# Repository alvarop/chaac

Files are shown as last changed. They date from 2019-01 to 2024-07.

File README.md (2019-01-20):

# Chaac - Weather station!

This is a work in progress for a wireless weather station project.

The project consists of:

* [Hardware](hw/) - Main development board design files
* [Firmware](fw/) - Code for the microcontroller
* [Software](sw/) - Python scripts to communicate with the weather station, log, and plot data

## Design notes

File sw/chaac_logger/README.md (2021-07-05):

# Chaac Logger Setup

## On Raspberry Pi

1. Clone repo to raspberry pi (or scp it over)
2. Run `./support/install_dependencies.sh` to get required software
3. Run `./support/setup.sh` to configure everything and start the server

If you just changed a few files and don't want to go through the whole pipenv process again, you can use `./support/update.sh`. This will just restart the services.

### Monitoring
To monitor packets arriving run:

`sudo tail -f /var/log/supervisor/chaac-logger-app-stdout---supervisor-KsDl4b.log`

Note that the last few characters, `KsDl4b` in this case, change everytime supervisor restarts. It's easy to just tab complete with whatever is there.

To check for errors, just replace stdout for stderr in the command.

## Local Development
Run `pipenv run python chaac_logger.py --port /dev/ttyUSB0 --db sqlite_db_filename.db`

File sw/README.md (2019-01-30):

# Chaac Software

## [chaac](chaac/)
The chaac directory has python files related to chaac packets and processing.

## [chaac_frontend](chaac_frontend/)
The chaac_frontend is a flask project with the web ui for Chaac. It displays the current weather as well as plots historical data

## [chaac_logger](chaac_logger/)
The chaac_logger takes care of receiving the serial data from the xbee radio, decoding, and saving it into the database.

## [scripts](scripts/)
The scripts directory has various useful (and in development) scripts.

## [serial_packet](serial_packet/)
The serial_packet directory has python files related to serial packets (one layer below the chaac packets).

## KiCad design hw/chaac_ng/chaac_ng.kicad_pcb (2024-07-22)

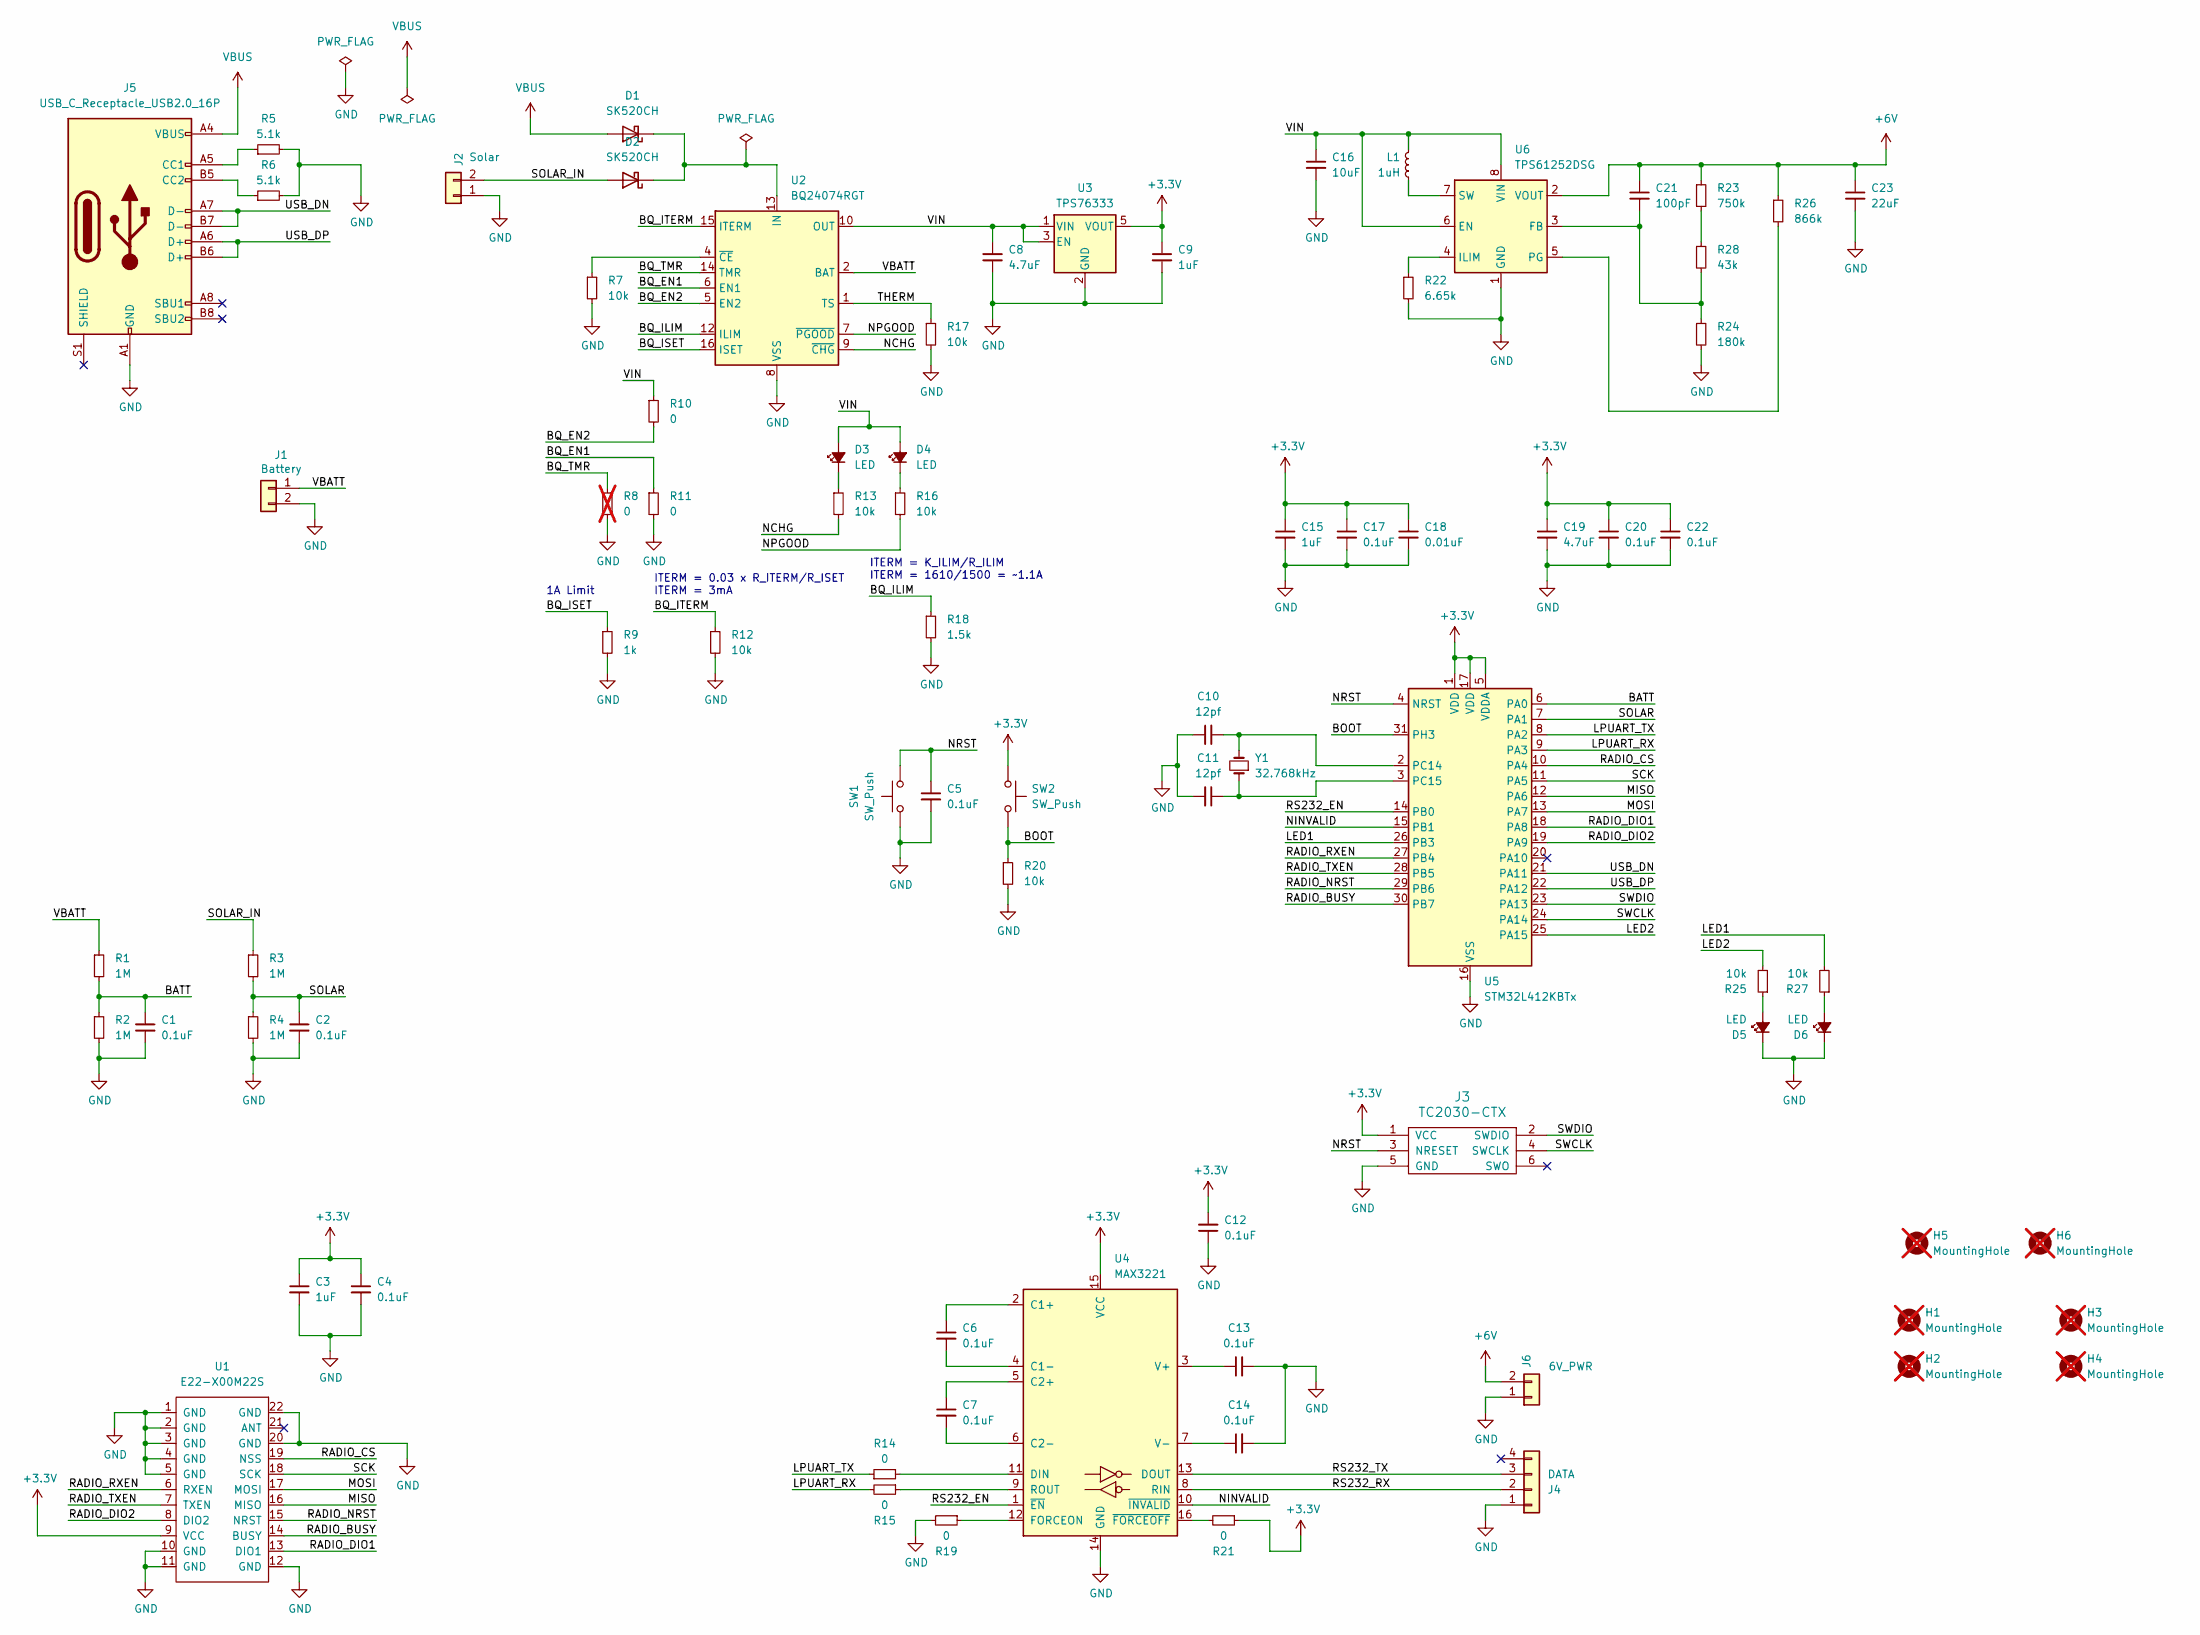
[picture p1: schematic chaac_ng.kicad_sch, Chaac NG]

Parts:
C1, C2, C4, C5, C6, C7, C12, C13, C14, C17, C20, C22: 0.1uF; C_0402_1005Metric; MPN CL05B104KB54PNC; LCSC C307331
C3, C9, C15: 1uF; C_0402_1005Metric; MPN CL05A105KA5NQNC; LCSC C52923
C8, C19: 4.7uF; C_0402_1005Metric; MPN CL05A475MP5NRNC; LCSC C23733
C10, C11: 12pf; C_0402_1005Metric; MPN 0402CG120J500NT; LCSC C1547
C16: 10uF; C_0603_1608Metric; MPN CL10A106MA8NRNC; LCSC C96446
C18: 0.01uF; C_0402_1005Metric; MPN CL05B103KB5NNNC; LCSC C15195
C21: 100pF; C_0402_1005Metric; MPN 0402CG101J500NT; LCSC C1546
C23: 22uF; C_1210_3225Metric; MPN TMK325B7226KMHP; LCSC C386098
D1, D2: SK520CH; SK520_DO-214AB; MPN SK520CHV6G; LCSC C483994
D3, D4, D5, D6: LED; LED_0603_1608Metric; MPN KT-0603R; LCSC C2286
H1, H2, H3, H4: MountingHole; MountingHole_3.2mm_M3; not fitted
H5, H6: MountingHole; ZIPTIE_HOLE_4x2mm; not fitted
J1: Battery; S2B-PH-SM4-TB; MPN S2B-PH-SM4-TB(LF)(SN); LCSC C295747
J2: Solar; TerminalBlock_TE_282834-2_1x02_P2.54mm_Horizontal; MPN 282834-2; LCSC C918120
J3: TC2030-CTX; TC2030-NL
J4: DATA; TerminalBlock_TE_282834-4_1x04_P2.54mm_Horizontal; MPN 282834-4; LCSC C918122
J5: USB_C_Receptacle_USB2.0_16P; USB-C-SMD_TYPE-C16PIN; MPN TYPE-C16PIN; LCSC C393939
J6: 6V_PWR; TerminalBlock_TE_282834-2_1x02_P2.54mm_Horizontal; MPN 282834-2; LCSC C918120
L1: 1uH; L_0806; MPN DFE201610E-1R0M=P2; LCSC C161082
R1, R2, R3, R4: 1M; R_0402_1005Metric; LCSC C26083
R5, R6: 5.1k; R_0402_1005Metric; LCSC C25905
R7, R12, R13, R16, R17, R20, R25, R27: 10k; R_0402_1005Metric; LCSC C25744
R8: 0; R_0402_1005Metric; LCSC C17168; not fitted
R9: 1k; R_0402_1005Metric; LCSC C11702
R10, R11, R14, R15, R19, R21: 0; R_0402_1005Metric; LCSC C17168
R18: 1.5k; R_0402_1005Metric; LCSC C25867
R22: 6.65k; R_0402_1005Metric; LCSC C227201
R23: 750k; R_0402_1005Metric; LCSC C137937
R24: 180k; R_0402_1005Metric; LCSC C138046
R26: 866k; R_0402_1005Metric; LCSC C227250
R28: 43k; R_0402_1005Metric; LCSC C227081
SW1, SW2: SW_Push; SW-SMD_L3.9-W3.0-P4.45; MPN SKRKAEE020; LCSC C115357
U1: E22-X00M22S; MPN E22-900M22S; LCSC C411293
U2: BQ24074RGT; VQFN-16-1EP_3x3mm_P0.5mm_EP1.6x1.6mm; MPN BQ24074RGTR; LCSC C54313
U3: TPS76333; SOT-23-5; MPN TCR3DF33,LM(CT; LCSC C146356
U4: MAX3221; TSSOP-16_4.4x5mm_P0.65mm; MPN MAX3221EIPWR; LCSC C484736
U5: STM32L412KBTx; LQFP-32_7x7mm_P0.8mm; MPN STM32L412KBT6; LCSC C529438
U6: TPS61252DSG; WSON-8-1EP_2x2mm_P0.5mm_EP0.9x1.6mm; MPN TPS61252DSGR; LCSC C128617
Y1: 32.768kHz; ABS05; MPN ABS05-32.768KHZ-9-T; LCSC C596929

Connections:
+3.3V: C3.1, C4.1, C9.1, C12.2, C15.1, C17.1, C18.1, C19.1, C20.1, C22.1, J3.1 (VCC), R21.1, SW2.1, U1.9 (VCC), U3.5 (VOUT), U4.15 (VCC), U5.1 (VDD), U5.5 (VDDA), U5.17 (VDD)
+6V: C21.1, C23.1, J6.2, R23.1, R26.1, U6.2 (VOUT)
/BATT: C1.1, R1.2, R2.1, U5.6 (PA0)
/BOOT: R20.1, SW2.2, U5.31 (PH3)
/BQ_EN1: R11.1, U2.6 (EN1)
/BQ_EN2: R10.2, U2.5 (EN2)
/BQ_ILIM: R18.1, U2.12 (ILIM)
/BQ_ISET: R9.1, U2.16 (ISET)
/BQ_ITERM: R12.1, U2.15 (ITERM)
/BQ_TMR: R8.1, U2.14 (TMR)
/LED1: R27.2, U5.26 (PB3)
/LED2: R25.2, U5.25 (PA15)
/LPUART_RX: R15.2, U5.9 (PA3)
/LPUART_TX: R14.1, U5.8 (PA2)
/MISO: U1.16 (MISO), U5.12 (PA6)
/MOSI: U1.17 (MOSI), U5.13 (PA7)
/NCHG: R13.2, U2.9 (~CHG)
/NINVALID: U4.10 (~INVALID), U5.15 (PB1)
/NPGOOD: R16.2, U2.7 (~PGOOD)
/NRST: C5.1, J3.3 (NRESET), SW1.2, U5.4 (NRST)
/RADIO_BUSY: U1.14 (BUSY), U5.30 (PB7)
/RADIO_CS: U1.19 (NSS), U5.10 (PA4)
/RADIO_DIO1: U1.13 (DIO1), U5.18 (PA8)
/RADIO_DIO2: U1.8 (DIO2), U5.19 (PA9)
/RADIO_NRST: U1.15 (NRST), U5.29 (PB6)
/RADIO_RXEN: U1.6 (RXEN), U5.27 (PB4)
/RADIO_TXEN: U1.7 (TXEN), U5.28 (PB5)
/RS232_EN: U4.1 (~EN), U5.14 (PB0)
/RS232_RX: J4.2, U4.8 (RIN)
/RS232_TX: J4.3, U4.13 (DOUT)
/SCK: U1.18 (SCK), U5.11 (PA5)
/SOLAR: C2.1, R3.2, R4.1, U5.7 (PA1)
/SOLAR_IN: D2.2 (A), J2.2, R3.1
/SWCLK: J3.4 (SWCLK), U5.24 (PA14)
/SWDIO: J3.2 (SWDIO), U5.23 (PA13)
/THERM: R17.1, U2.1 (TS)
/USB_DN: J5.A7 (D-), J5.B7 (D-), U5.21 (PA11)
/USB_DP: J5.A6 (D+), J5.B6 (D+), U5.22 (PA12)
/VBATT: J1.1, R1.1, U2.2 (BAT), U2.3 (BAT)
/VIN: C8.1, C16.1, D3.2 (A), D4.2 (A), L1.1, R10.1, U2.10 (OUT), U2.11 (OUT), U3.1 (VIN), U3.3 (EN), U6.6 (EN), U6.8 (VIN)
GND: C1.2, C2.2, C3.2, C4.2, C5.2, C8.2, C9.2, C10.1, C11.2, C12.1, C13.2, C14.2, C15.2, C16.2, C17.2, C18.2, C19.2, C20.2, C22.2, C23.2, D5.1 (K), D6.1 (K), J1.2, J2.1, J3.5 (GND), J4.1, J5.A1 (GND), J5.A12 (GND), J5.B1 (GND), J5.B12 (GND), J6.1, R2.2, R4.2, R5.2, R6.2, R7.2, R8.2, R9.2, R11.2, R12.2, R17.2, R18.2, R19.2, R20.2, R22.2, R24.2, SW1.1, U1.1 (GND), U1.2 (GND), U1.3 (GND), U1.4 (GND), U1.5 (GND), U1.10 (GND), U1.11 (GND), U1.12 (GND), U1.20 (GND), U1.22 (GND), U2.8 (VSS), U2.17 (VSS), U3.2 (GND), U4.14 (GND), U5.16 (VSS), U5.32 (VSS), U6.1 (GND), U6.9 (GND)
unnamed: D1.1 (K), D2.1 (K), U2.13 (IN)
unnamed: D3.1 (K), R13.1
unnamed: D4.1 (K), R16.1
unnamed: D5.2 (A), R25.1
unnamed: D6.2 (A), R27.1
unnamed: J5.A5 (CC1), R5.1
unnamed: J5.B5 (CC2), R6.1
unnamed: R23.2, R28.1
unnamed: R7.1, U2.4 (~CE)
unnamed: C6.1, U4.2 (C1+)
unnamed: C6.2, U4.4 (C1-)
unnamed: C7.1, U4.5 (C2+)
unnamed: C7.2, U4.6 (C2-)
unnamed: R14.2, U4.11 (DIN)
unnamed: R19.1, U4.12 (FORCEON)
unnamed: R15.1, U4.9 (ROUT)
unnamed: C13.1, U4.3 (V+)
unnamed: C14.1, U4.7 (V-)
unnamed: R21.2, U4.16 (~FORCEOFF)
unnamed: C10.2, U5.2 (PC14), Y1.2
unnamed: C11.1, U5.3 (PC15), Y1.1
unnamed: C21.2, R24.1, R28.2, U6.3 (FB)
unnamed: R22.1, U6.4 (ILIM)
unnamed: R26.2, U6.5 (PG)
unnamed: L1.2, U6.7 (SW)
VBUS: D1.2 (A), J5.A4 (VBUS), J5.A9 (VBUS), J5.B4 (VBUS), J5.B9 (VBUS)

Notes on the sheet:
ITERM = K_ILIM/R_ILIM ITERM = 1610/1500 = ~1.1A
ITERM = 0.03 x R_ITERM/R_ISET ITERM = 3mA
1A Limit

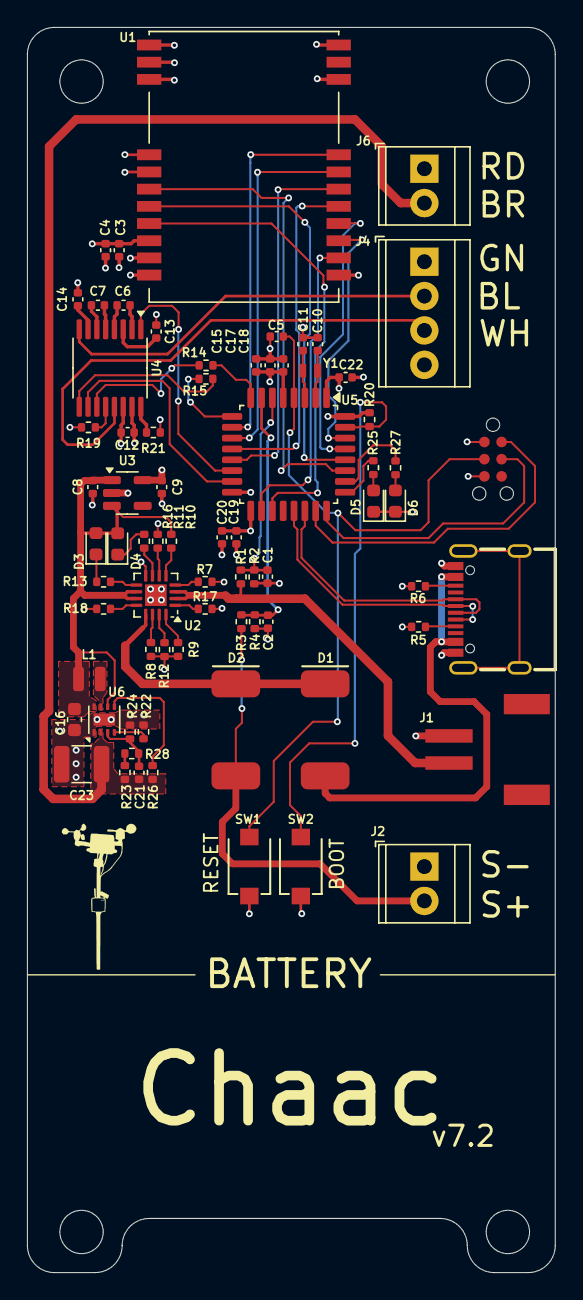
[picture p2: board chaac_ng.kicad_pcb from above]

Board: 4 copper layers, 39.0 x 92.0 mm, 79 parts (0 on the bottom side), 67 nets.

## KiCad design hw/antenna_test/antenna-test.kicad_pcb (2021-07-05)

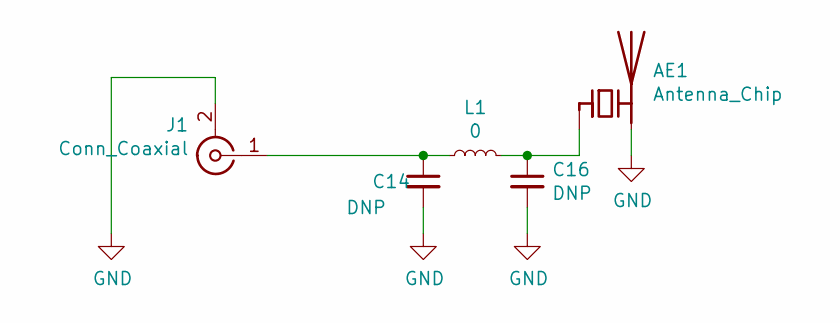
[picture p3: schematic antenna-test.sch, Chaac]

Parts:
AE1: Antenna_Chip; W3211
C14, C16: DNP; C_0402_1005Metric
J1: Conn_Coaxial; TE-2337019-1
L1: 0; L_0402_1005Metric

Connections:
GND: AE1.2 (PCB_Trace), C14.2, C16.2, J1.2 (Ext)
unnamed: AE1.1 (FEED), C16.1, L1.2
unnamed: C14.1, J1.1 (In), L1.1

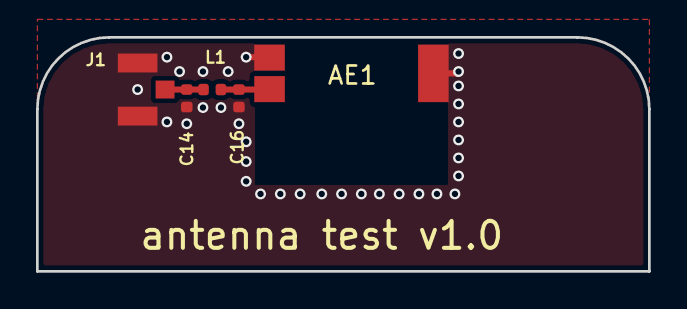
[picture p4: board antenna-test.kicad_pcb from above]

Board: 4 copper layers, 34.0 x 13.0 mm, 5 parts (0 on the bottom side), 3 nets.

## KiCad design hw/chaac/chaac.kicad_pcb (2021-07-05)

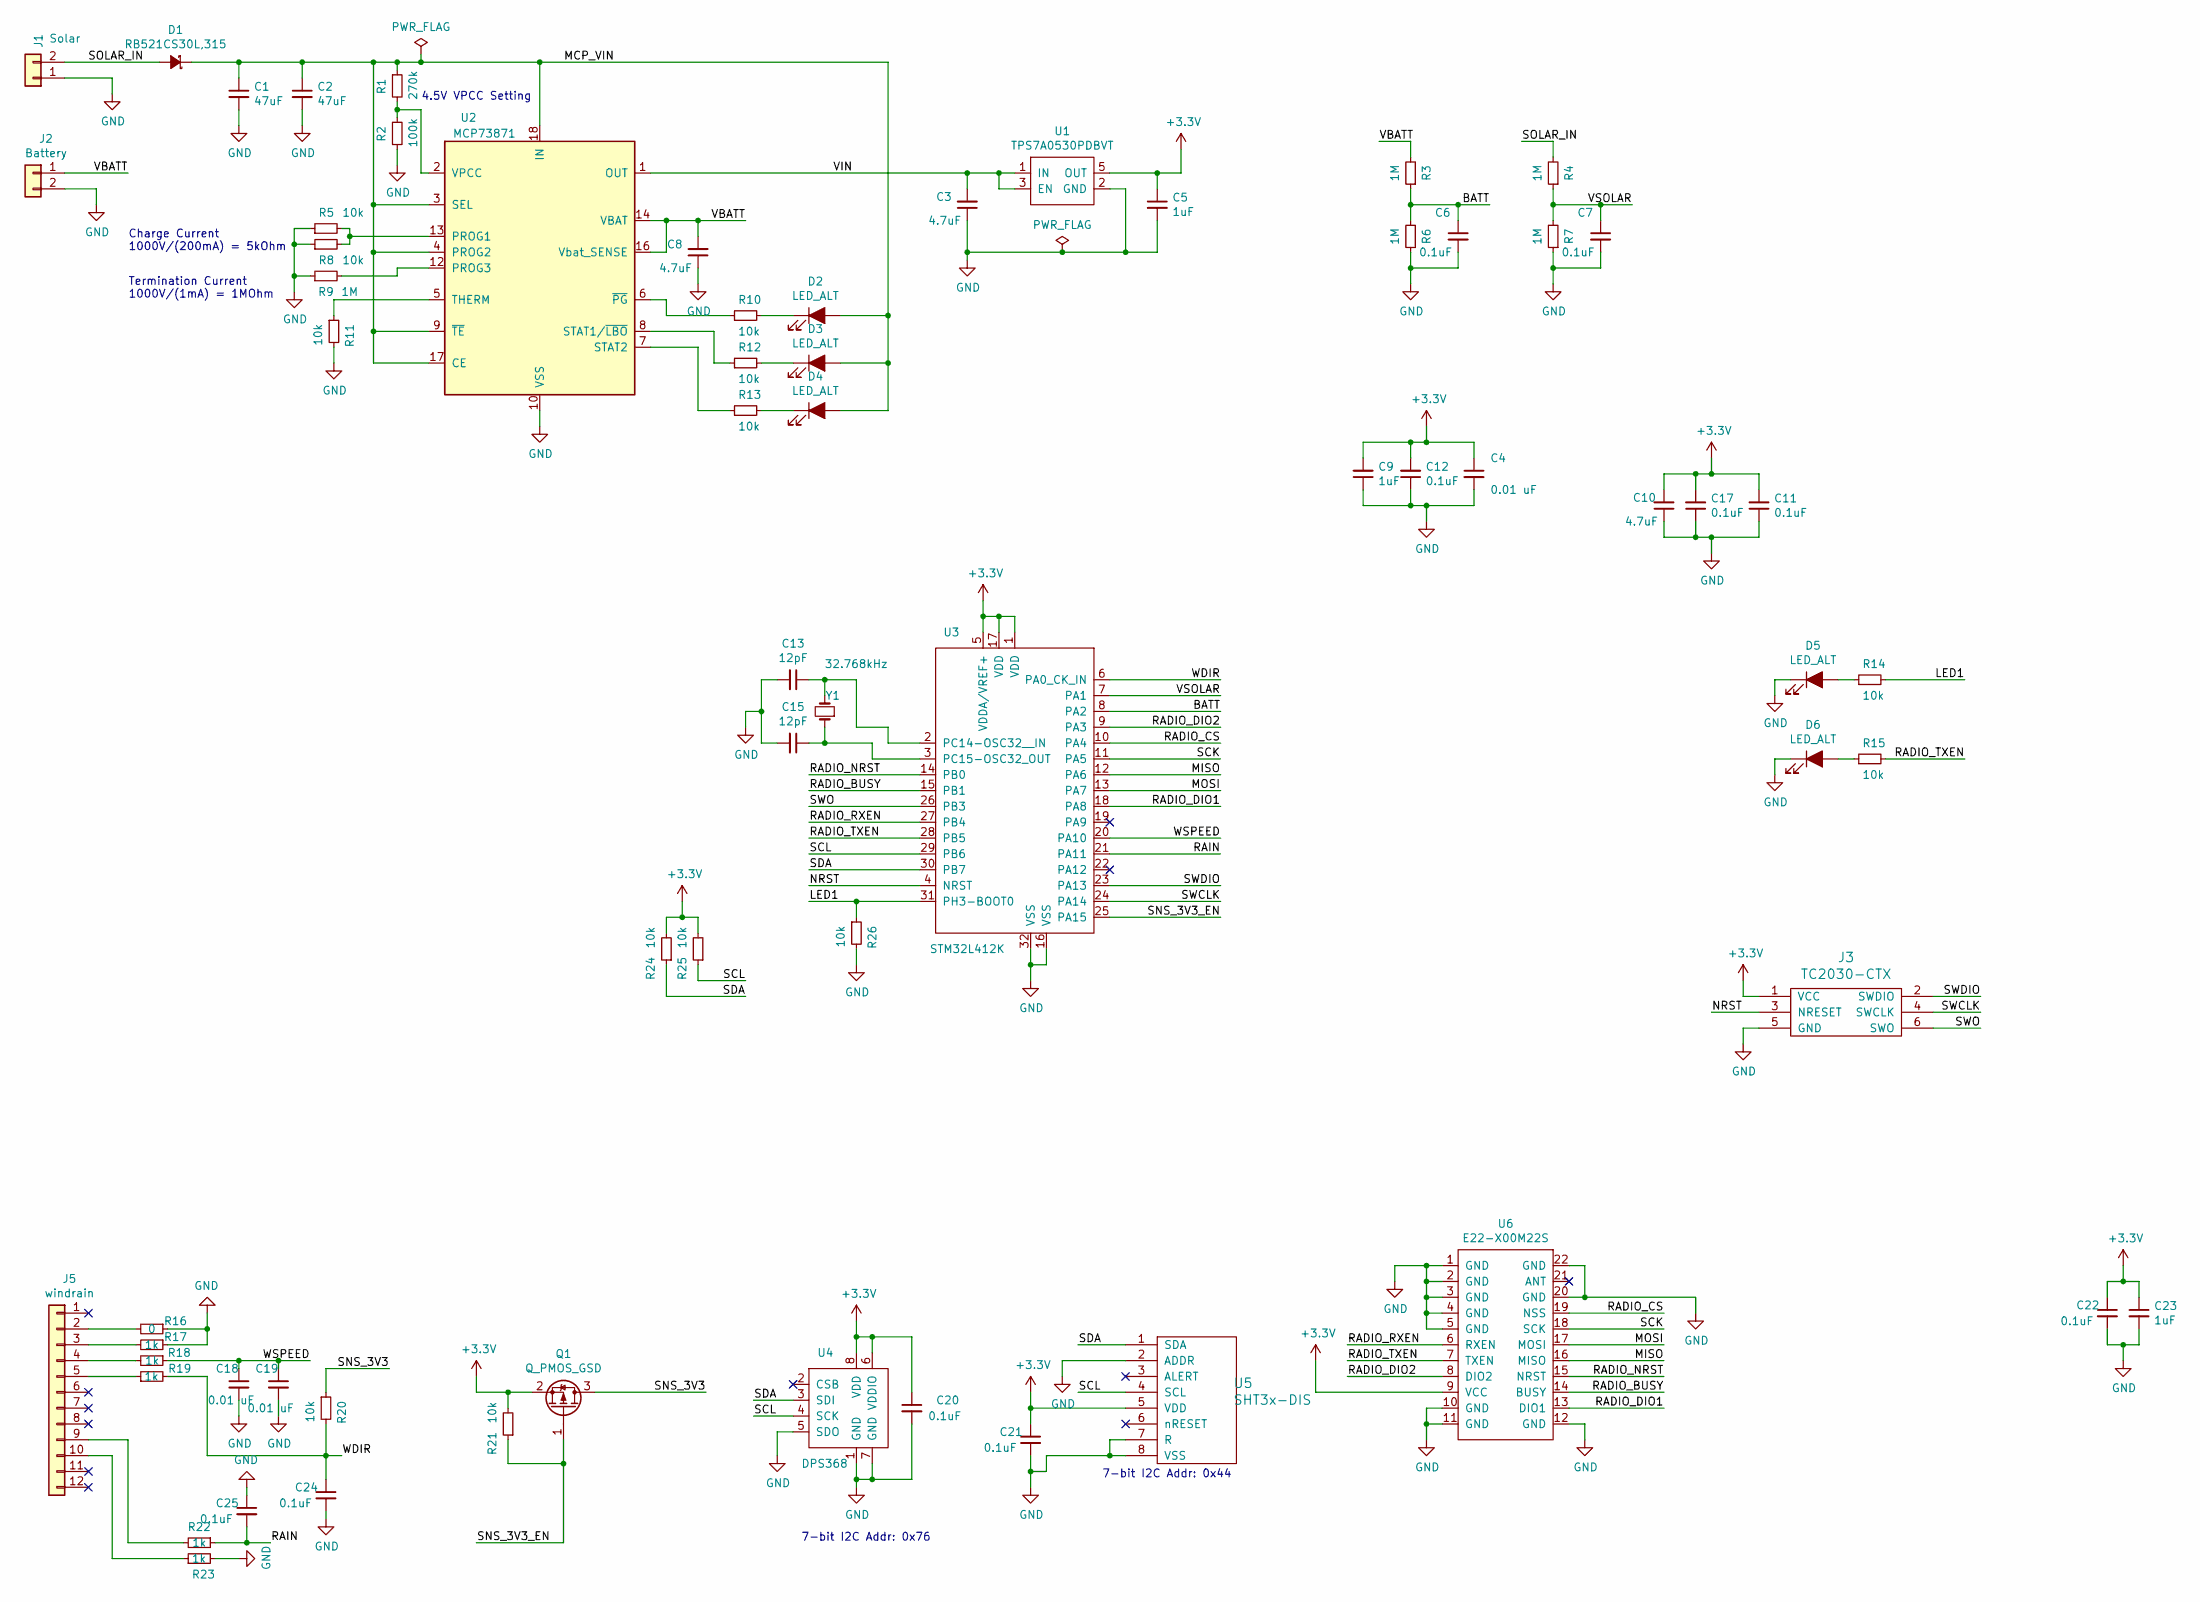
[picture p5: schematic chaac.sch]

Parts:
C1, C2: 47uF; C_1206_3216Metric; MPN CL31A476MPHNNNE
C3, C8, C10: 4.7uF; C_0402_1005Metric; MPN CL05A475MP5NRNC
C4, C18, C19: 0.01 uF; C_0402_1005Metric; MPN CL05B103KB5NNNC
C5, C9, C23: 1uF; C_0402_1005Metric; MPN C1005X5R1V105K050BE
C6, C7, C11, C12, C17, C20, C21, C22, C24, C25: 0.1uF; C_0402_1005Metric; MPN GRM155R61A104KA01D
C13, C15: 12pF; C_0402_1005Metric; MPN C0402C120J5GACTU
D1: RB521CS30L,315; RB521CS30L; MPN RB521CS30L,315
D2, D3, D4, D5, D6: LED_ALT; LED_0603_1608Metric; MPN SML-D12U1WT86
J1: Solar; TerminalBlock_TE_282834-2_1x02_P2.54mm_Horizontal; MPN 282834-2
J2: Battery; S2B-PH-SM4-TB; MPN S2B-PH-SM4-TB(LF)(SN)
J3: TC2030-CTX; TC2030-NL
J5: windrain; 043814-6621; MPN 0438146621
Q1: Q_PMOS_GSD; SOT-23; MPN FDV304P
R1: 270k; R_0402_1005Metric; MPN RC0402FR-07270KL
R2: 100k; R_0402_1005Metric; MPN RC0402FR-07100KL
R3, R4, R6, R7, R9: 1M; R_0402_1005Metric; MPN CRCW04021M00FKEDC
R5, R8: 10k; R_0402_1005Metric; MPN RC0402FR-07100KL
R10, R11, R12, R13, R14, R15, R20, R21, R24, R25, R26: 10k; R_0402_1005Metric; MPN RC0402JR-0710KL
R16: 0; R_0402_1005Metric
R17, R18, R19, R22, R23: 1k; R_0402_1005Metric; MPN CRG0402J1K0
U1: TPS7A0530PDBVT; SOT-23(M5); MPN TPS7A0530PDBVT
U2: MCP73871; MPN MCP73871T-2CCI/ML
U3: STM32L412K; UFQFPN32-ALT; MPN STM32L412KBU6
U4: DPS368; MPN DPS368XTSA1
U5: SHT3x-DIS; SHT3x; MPN SHT31-DIS-F2.5KS
U6: E22-X00M22S
Y1: 32.768kHz; ABS05; MPN ABS05-32.768KHZ-9-T

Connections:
+3V3: C4.1, C5.1, C9.2, C10.2, C11.2, C12.2, C17.2, C20.1, C21.1, C22.1, C23.1, J3.1 (VCC), Q1.2 (S), R21.2, R24.2, R25.2, U1.5 (OUT), U3.1 (VDD), U3.5 (VDDA/VREF+), U3.17 (VDD), U4.6 (VDDIO), U4.8 (VDD), U5.5 (VDD), U6.9 (VCC)
/BATT: C6.1, R3.1, R6.2, U3.8 (PA2)
/LED1: R14.2, R26.1, U3.31 (PH3-BOOT0)
/MCP_VIN: C1.1, C2.1, D1.1 (K), D2.2 (A), D3.2 (A), D4.2 (A), R1.1, U2.3 (SEL), U2.4 (PROG2), U2.9 (~TE), U2.17 (CE), U2.18 (IN), U2.19 (IN)
/MISO: U3.12 (PA6), U6.16 (MISO)
/MOSI: U3.13 (PA7), U6.17 (MOSI)
/NRST: J3.3 (NRESET), U3.4 (NRST)
/RADIO_BUSY: U3.15 (PB1), U6.14 (BUSY)
/RADIO_CS: U3.10 (PA4), U6.19 (NSS)
/RADIO_DIO1: U3.18 (PA8), U6.13 (DIO1)
/RADIO_DIO2: U3.9 (PA3), U6.8 (DIO2)
/RADIO_NRST: U3.14 (PB0), U6.15 (NRST)
/RADIO_RXEN: U3.27 (PB4), U6.6 (RXEN)
/RADIO_TXEN: R15.2, U3.28 (PB5), U6.7 (TXEN)
/RAIN: C25.2, R22.1, U3.21 (PA11)
/SCK: U3.11 (PA5), U6.18 (SCK)
/SCL: R25.1, U3.29 (PB6), U4.4 (SCK), U5.4 (SCL)
/SDA: R24.1, U3.30 (PB7), U4.3 (SDI), U5.1 (SDA)
/SNS_3V3: Q1.3 (D), R20.1
/SNS_3V3_EN: Q1.1 (G), R21.1, U3.25 (PA15)
/SOLAR_IN: D1.2 (A), J1.2, R4.2
/SWCLK: J3.4 (SWCLK), U3.24 (PA14)
/SWDIO: J3.2 (SWDIO), U3.23 (PA13)
/SWO: J3.6 (SWO), U3.26 (PB3)
/VBATT: C8.2, J2.1, R3.2, U2.14 (VBAT), U2.15 (VBAT), U2.16 (Vbat_SENSE)
/VIN: C3.2, U1.1 (IN), U1.3 (EN), U2.1 (OUT), U2.20 (OUT)
/VSOLAR: C7.1, R4.1, R7.2, U3.7 (PA1)
/WDIR: C24.1, R19.2, R20.2, U3.6 (PA0_CK_IN)
/WSPEED: C18.1, C19.1, R18.1, U3.20 (PA10)
GND: C1.2, C2.2, C3.1, C4.2, C5.2, C6.2, C7.2, C8.1, C9.1, C10.1, C11.1, C12.1, C13.2, C15.2, C17.1, C18.2, C19.2, C20.2, C21.2, C22.2, C23.2, C24.2, C25.1, D5.1 (K), D6.1 (K), J1.1, J2.2, J3.5 (GND), R2.2, R5.1, R6.1, R7.1, R8.1, R9.1, R11.2, R16.1, R17.1, R23.2, R26.2, U1.2 (GND), U2.10 (VSS), U2.11 (VSS), U2.21 (VSS), U3.16 (VSS), U3.32 (VSS), U4.1 (GND), U4.5 (SDO), U4.7 (GND), U5.2 (ADDR), U5.7 (R), U5.8 (VSS), U6.1 (GND), U6.2 (GND), U6.3 (GND), U6.4 (GND), U6.5 (GND), U6.10 (GND), U6.11 (GND), U6.12 (GND), U6.20 (GND), U6.22 (GND)
unnamed: C13.1, U3.2 (PC14-OSC32__IN), Y1.2
unnamed: C15.1, U3.3 (PC15-OSC32_OUT), Y1.1
unnamed: D2.1 (K), R10.2
unnamed: D3.1 (K), R12.2
unnamed: D4.1 (K), R13.2
unnamed: D5.2 (A), R14.1
unnamed: D6.2 (A), R15.1
unnamed: J5.2, R16.2
unnamed: J5.3, R17.2
unnamed: J5.4, R18.2
unnamed: J5.5, R19.1
unnamed: J5.9, R22.2
unnamed: J5.10, R23.1
unnamed: R1.2, R2.1, U2.2 (VPCC)
unnamed: R5.2, R8.2, U2.13 (PROG1)
unnamed: R9.2, U2.12 (PROG3)
unnamed: R10.1, U2.6 (~PG~)
unnamed: R11.1, U2.5 (THERM)
unnamed: R12.1, U2.8 (STAT1/~LBO~)
unnamed: R13.1, U2.7 (STAT2)

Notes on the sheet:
7-bit I2C Addr: 0x76
7-bit I2C Addr: 0x44
Charge Current 1000V/(200mA) = 5kOhm
Termination Current 1000V/(1mA) = 1MOhm
4.5V VPCC Setting

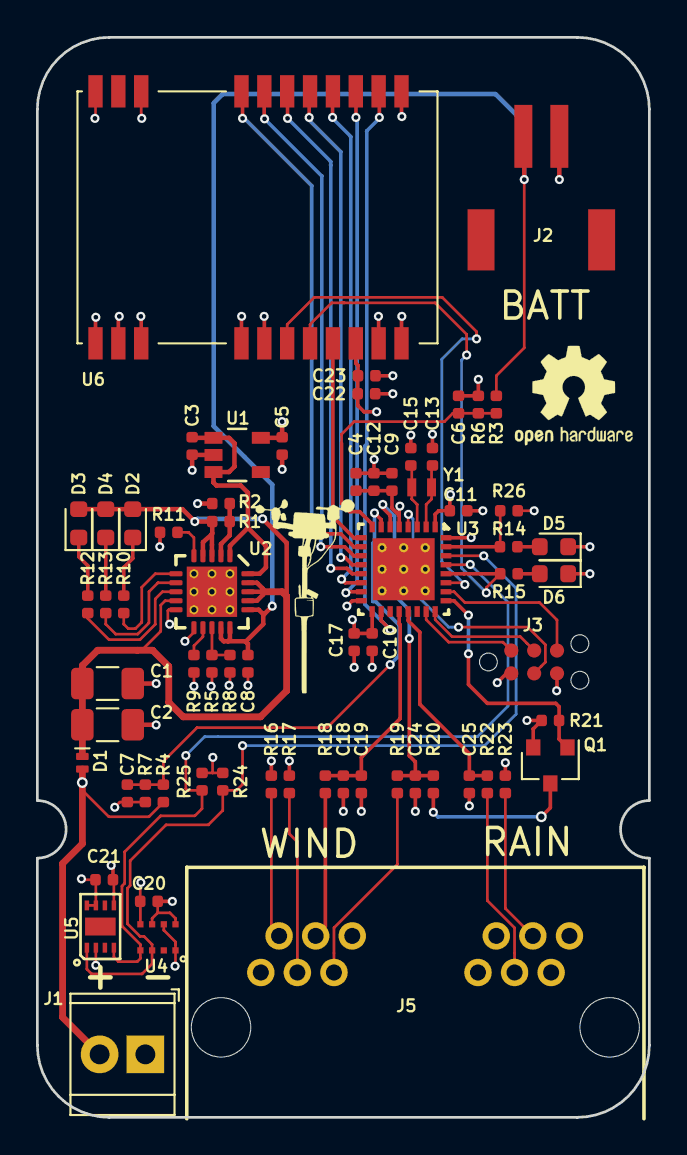
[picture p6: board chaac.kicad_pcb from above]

Board: 4 copper layers, 34.0 x 60.0 mm, 67 parts (0 on the bottom side), 50 nets.

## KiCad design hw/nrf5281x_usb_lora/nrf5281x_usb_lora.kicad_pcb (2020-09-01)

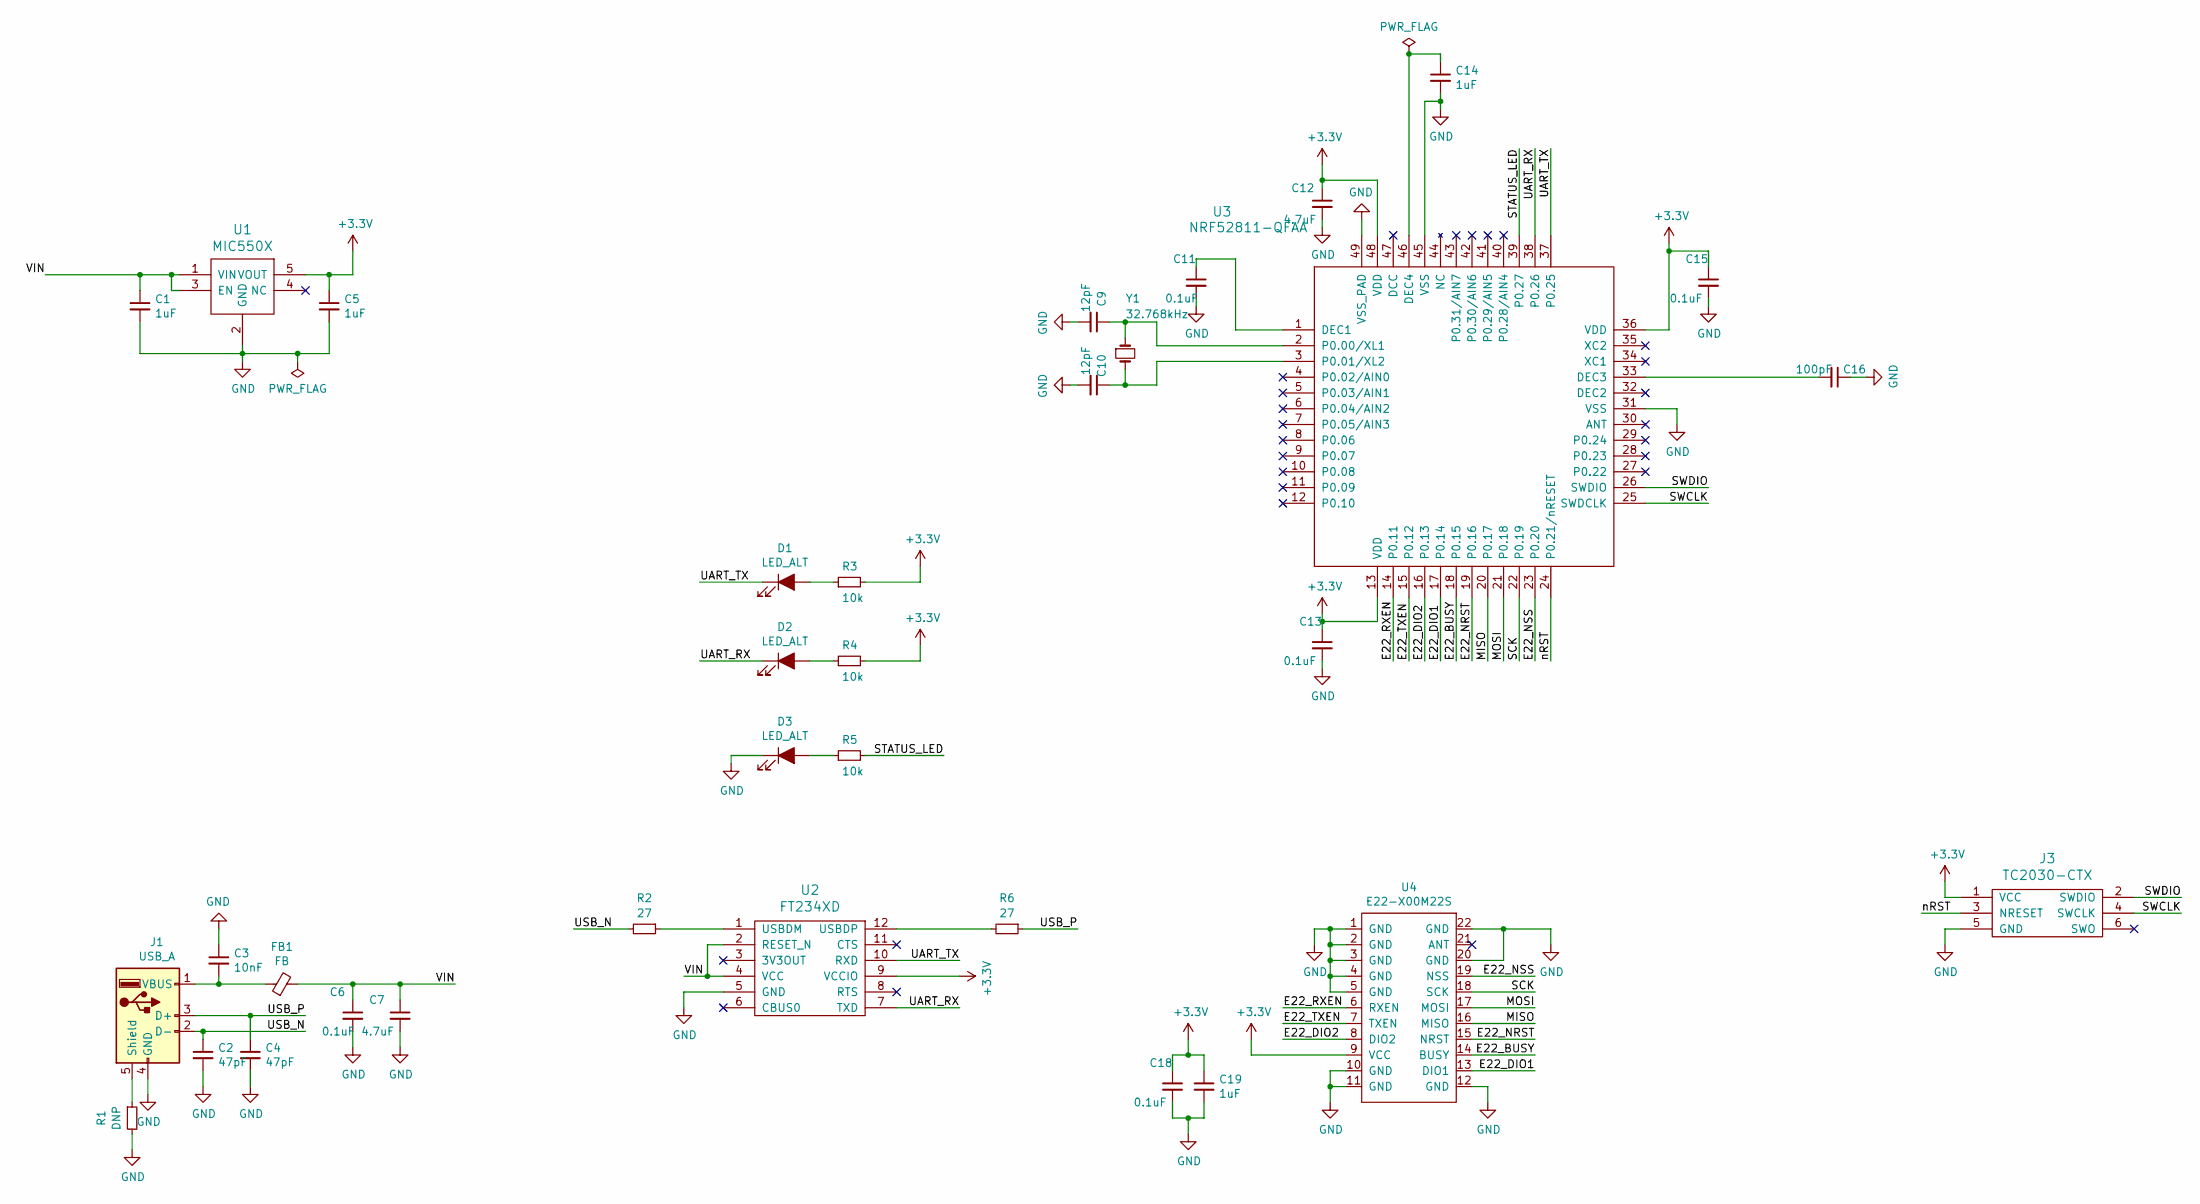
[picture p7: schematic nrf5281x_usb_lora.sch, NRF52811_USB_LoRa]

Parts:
C1, C5, C14, C19: 1uF; C_0402_1005Metric; MPN CC0402KRX5R5BB105
C2, C4: 47pF; C_0402_1005Metric; MPN C0402C470K5GACTU
C3: 10nF; C_0402_1005Metric; MPN CL05B103KB5NNNC
C6, C11, C13, C15, C18: 0.1uF; C_0402_1005Metric; MPN GRM155R61A104KA01D
C7, C12: 4.7uF; C_0603_1608Metric; MPN CL10B475KQ8NQNC
C9, C10: 12pF; C_0402_1005Metric; MPN C0402C120J5GACTU
C16: 100pF; C_0402_1005Metric; MPN UMK105CG101JV-F
D1, D2, D3: LED_ALT; LED_0402_1005Metric; MPN QBLP595-IG
FB1: FB; L_0402_1005Metric; MPN BLM15AG601SN1D
J1: USB_A; MOLEX-0480371000; MPN 0480371000
J3: TC2030-CTX; TC2030-NL
R1: DNP; R_0402_1005Metric
R2, R6: 27; R_0402_1005Metric; MPN RC0402JR-0727RL
R3, R4, R5: 10k; R_0402_1005Metric; MPN RC0402JR-0710KL
U1: MIC550X; SOT-23(M5); MPN MIC5504-3.3YM5-TR
U2: FT234XD; FTDI_DFN12; MPN FT234XD-R
U3: NRF52811-QFAA; NRF52811-QFN48-VIAS; MPN ‎NRF52811-QFAA-R‎
U4: E22-X00M22S
Y1: 32.768kHz; ABS05; MPN ABS05-32.768KHZ-9-T

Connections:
+3V3: C5.1, C12.1, C13.1, C15.1, C18.1, C19.1, J3.1 (VCC), R3.2, R4.2, U1.5 (VOUT), U2.9 (VCCIO), U3.13 (VDD), U3.36 (VDD), U3.48 (VDD), U4.9 (VCC)
/E22_BUSY: U3.18 (P0.15), U4.14 (BUSY)
/E22_DIO1: U3.17 (P0.14), U4.13 (DIO1)
/E22_DIO2: U3.16 (P0.13), U4.8 (DIO2)
/E22_NRST: U3.19 (P0.16), U4.15 (NRST)
/E22_NSS: U3.23 (P0.20), U4.19 (NSS)
/E22_RXEN: U3.14 (P0.11), U4.6 (RXEN)
/E22_TXEN: U3.15 (P0.12), U4.7 (TXEN)
/MISO: U3.20 (P0.17), U4.16 (MISO)
/MOSI: U3.21 (P0.18), U4.17 (MOSI)
/SCK: U3.22 (P0.19), U4.18 (SCK)
/STATUS_LED: R5.2, U3.39 (P0.27)
/SWCLK: J3.4 (SWCLK), U3.25 (SWDCLK)
/SWDIO: J3.2 (SWDIO), U3.26 (SWDIO)
/UART_RX: D2.1 (K), U2.7 (TXD), U3.38 (P0.26)
/UART_TX: D1.1 (K), U2.10 (RXD), U3.37 (P0.25)
/USB_N: C2.1, J1.2 (D-), R2.2
/USB_P: C4.1, J1.3 (D+), R6.1
/VIN: C1.1, C6.1, C7.1, FB1.2, U1.1 (VIN), U1.3 (EN), U2.2 (RESET_N), U2.4 (VCC)
/nRST: J3.3 (NRESET), U3.24 (P0.21/nRESET)
GND: C1.2, C2.2, C3.1, C4.2, C5.2, C6.2, C7.2, C9.2, C10.2, C11.2, C12.2, C13.2, C14.2, C15.2, C16.1, C18.2, C19.2, D3.1 (K), J1.4 (GND), J3.5 (GND), R1.2, U1.2 (GND), U2.5 (GND), U3.31 (VSS), U3.45 (VSS), U3.49 (VSS_PAD), U4.1 (GND), U4.2 (GND), U4.3 (GND), U4.4 (GND), U4.5 (GND), U4.10 (GND), U4.11 (GND), U4.12 (GND), U4.20 (GND), U4.22 (GND)
unnamed: C3.2, FB1.1, J1.1 (VBUS)
unnamed: C9.1, U3.2 (P0.00/XL1), Y1.1
unnamed: C10.1, U3.3 (P0.01/XL2), Y1.2
unnamed: C11.1, U3.1 (DEC1)
unnamed: C14.1, U3.46 (DEC4)
unnamed: C16.2, U3.33 (DEC3)
unnamed: D1.2 (A), R3.1
unnamed: D2.2 (A), R4.1
unnamed: D3.2 (A), R5.1
unnamed: J1.5 (Shield), R1.1
unnamed: R2.1, U2.1 (USBDM)
unnamed: R6.2, U2.12 (USBDP)

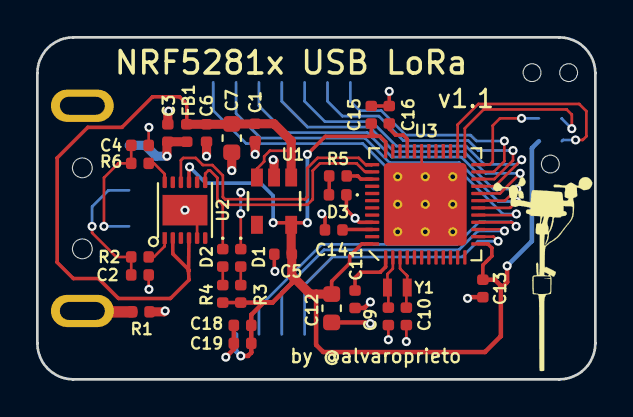
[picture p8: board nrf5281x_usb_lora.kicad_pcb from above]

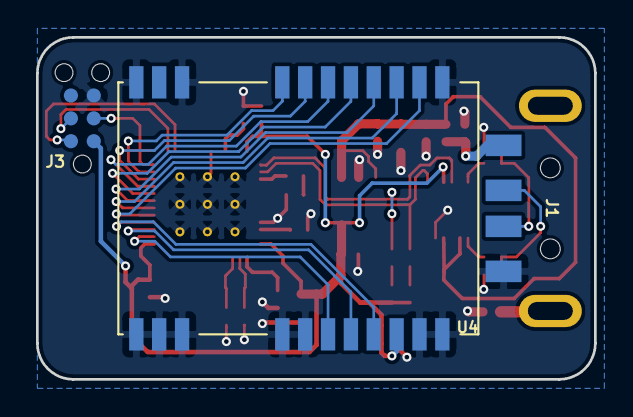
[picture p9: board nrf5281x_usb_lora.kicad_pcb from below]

Board: 2 copper layers, 31.0 x 19.0 mm, 34 parts (3 on the bottom side), 33 nets.

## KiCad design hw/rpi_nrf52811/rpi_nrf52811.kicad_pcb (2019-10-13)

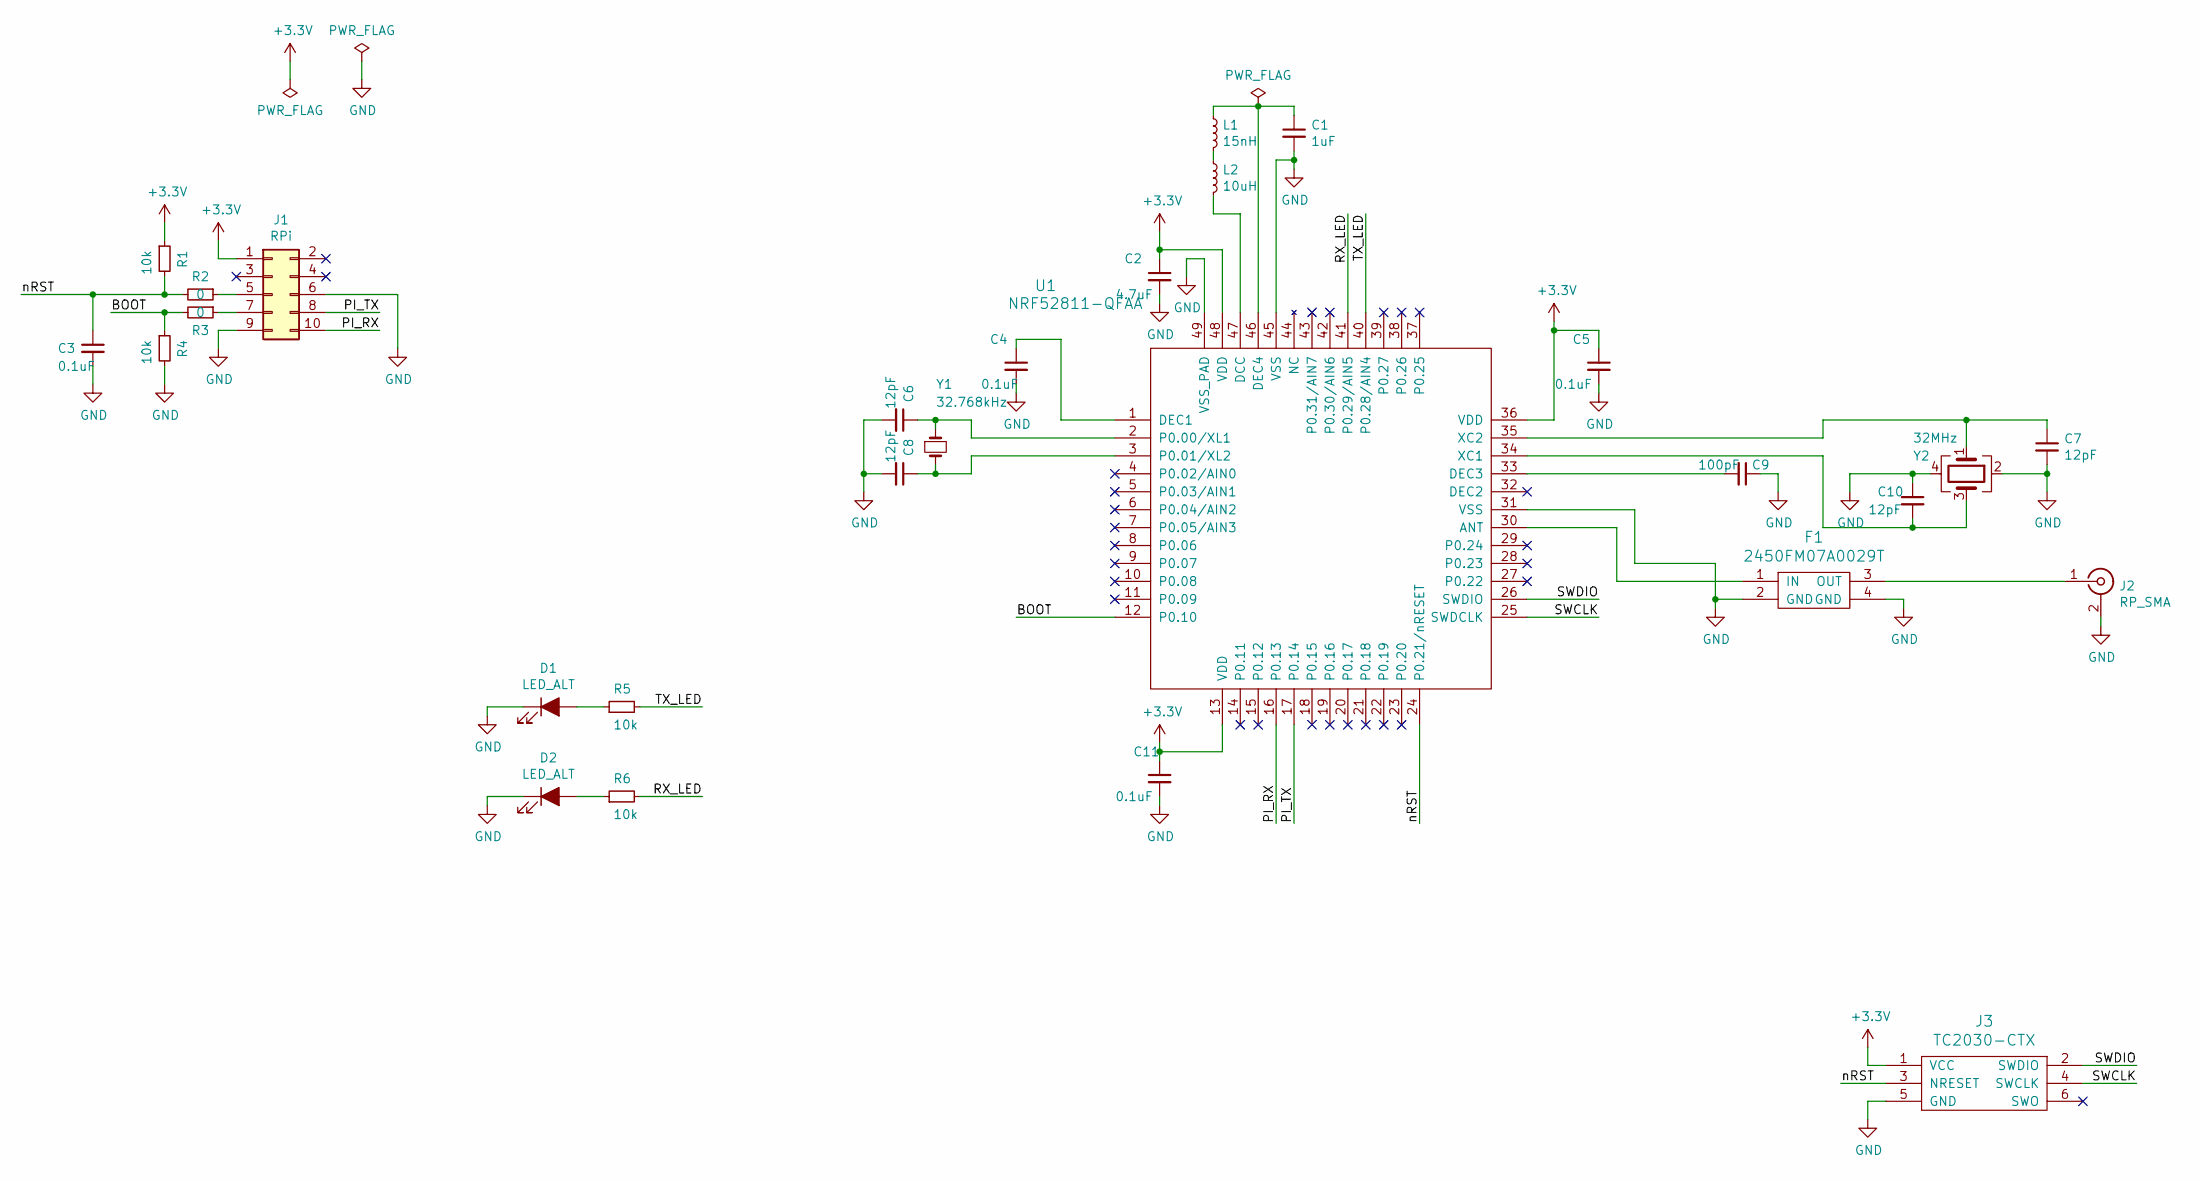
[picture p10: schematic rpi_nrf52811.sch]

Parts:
C1: 1uF; C_0402_1005Metric; MPN CC0402KRX5R5BB105
C2: 4.7uF; C_0603_1608Metric; MPN CL10B475KQ8NQNC
C3, C4, C5, C11: 0.1uF; C_0402_1005Metric; MPN GRM155R61A104KA01D
C6, C7, C8, C10: 12pF; C_0402_1005Metric; MPN C0402C120J5GACTU
C9: 100pF; C_0402_1005Metric; MPN UMK105CG101JV-F
D1, D2: LED_ALT; LED_0402_1005Metric; MPN QBLP595-IG
F1: 2450FM07A0029T; MPN 2450FM07A0029T
J1: RPi; PinSocket_2x05_P2.54mm_Vertical_SMD; MPN NPPC052KFMS-RC
J2: RP_SMA; SMA_Samtec_SMA-J-P-H-ST-EM1_EdgeMount; MPN CONREVSMA003.062
J3: TC2030-CTX; TC2030-NL
L1: 15nH; L_0402_1005Metric; MPN HK100515NJ-T‎
L2: 10uH; L_0603_1608Metric; MPN ‎LQM18FN100M00D‎
R1, R4, R5, R6: 10k; R_0402_1005Metric; MPN RC0402JR-0710KL
R2, R3: 0; R_0402_1005Metric; MPN RC1005J000CS
U1: NRF52811-QFAA; NRF52811-QFN48; MPN ‎NRF52811-QFAA-R‎
Y1: 32.768kHz; Crystal_SMD_3215-2Pin_3.2x1.5mm; MPN FC-135 32.7680KA-AC0
Y2: 32MHz; Crystal_SMD_2016-4Pin_2.0x1.6mm; MPN CX2016DB32000D0FLJCC

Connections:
+3V3: C2.1, C5.1, C11.1, J1.1, J3.1 (VCC), R1.1, U1.13 (VDD), U1.36 (VDD), U1.48 (VDD)
/BOOT: R3.2, R4.1, U1.12 (P0.10)
/PI_RX: J1.10, U1.16 (P0.13)
/PI_TX: J1.8, U1.17 (P0.14)
/RX_LED: R6.2, U1.41 (P0.29/AIN5)
/SWCLK: J3.4 (SWCLK), U1.25 (SWDCLK)
/SWDIO: J3.2 (SWDIO), U1.26 (SWDIO)
/TX_LED: R5.2, U1.40 (P0.28/AIN4)
/nRST: C3.1, J3.3 (NRESET), R1.2, R2.2, U1.24 (P0.21/nRESET)
GND: C1.2, C2.2, C3.2, C4.2, C5.2, C6.2, C7.2, C8.2, C9.1, C10.1, C11.2, D1.1 (K), D2.1 (K), F1.2 (GND), F1.4 (GND), J1.6, J1.9, J2.2 (Ext), J3.5 (GND), R4.2, U1.31 (VSS), U1.45 (VSS), U1.49 (VSS_PAD), Y2.2, Y2.4
unnamed: C1.1, L1.1, U1.46 (DEC4)
unnamed: C4.1, U1.1 (DEC1)
unnamed: C6.1, U1.2 (P0.00/XL1), Y1.1
unnamed: C7.1, U1.35 (XC2), Y2.1
unnamed: C8.1, U1.3 (P0.01/XL2), Y1.2
unnamed: C9.2, U1.33 (DEC3)
unnamed: C10.2, U1.34 (XC1), Y2.3
unnamed: D1.2 (A), R5.1
unnamed: D2.2 (A), R6.1
unnamed: F1.1 (IN), U1.30 (ANT)
unnamed: F1.3 (OUT), J2.1 (In)
unnamed: J1.5, R2.1
unnamed: J1.7, R3.1
unnamed: L1.2, L2.1
unnamed: L2.2, U1.47 (DCC)

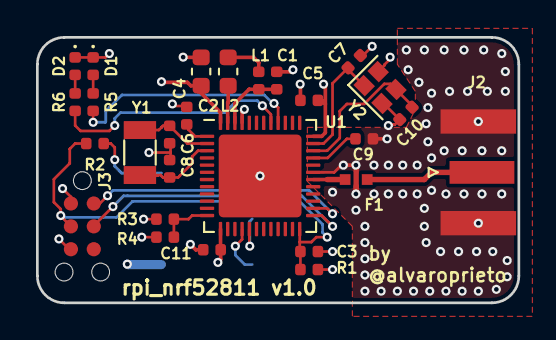
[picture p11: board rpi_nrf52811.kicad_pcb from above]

Board: 4 copper layers, 26.8 x 14.8 mm, 28 parts (1 on the bottom side), 25 nets.

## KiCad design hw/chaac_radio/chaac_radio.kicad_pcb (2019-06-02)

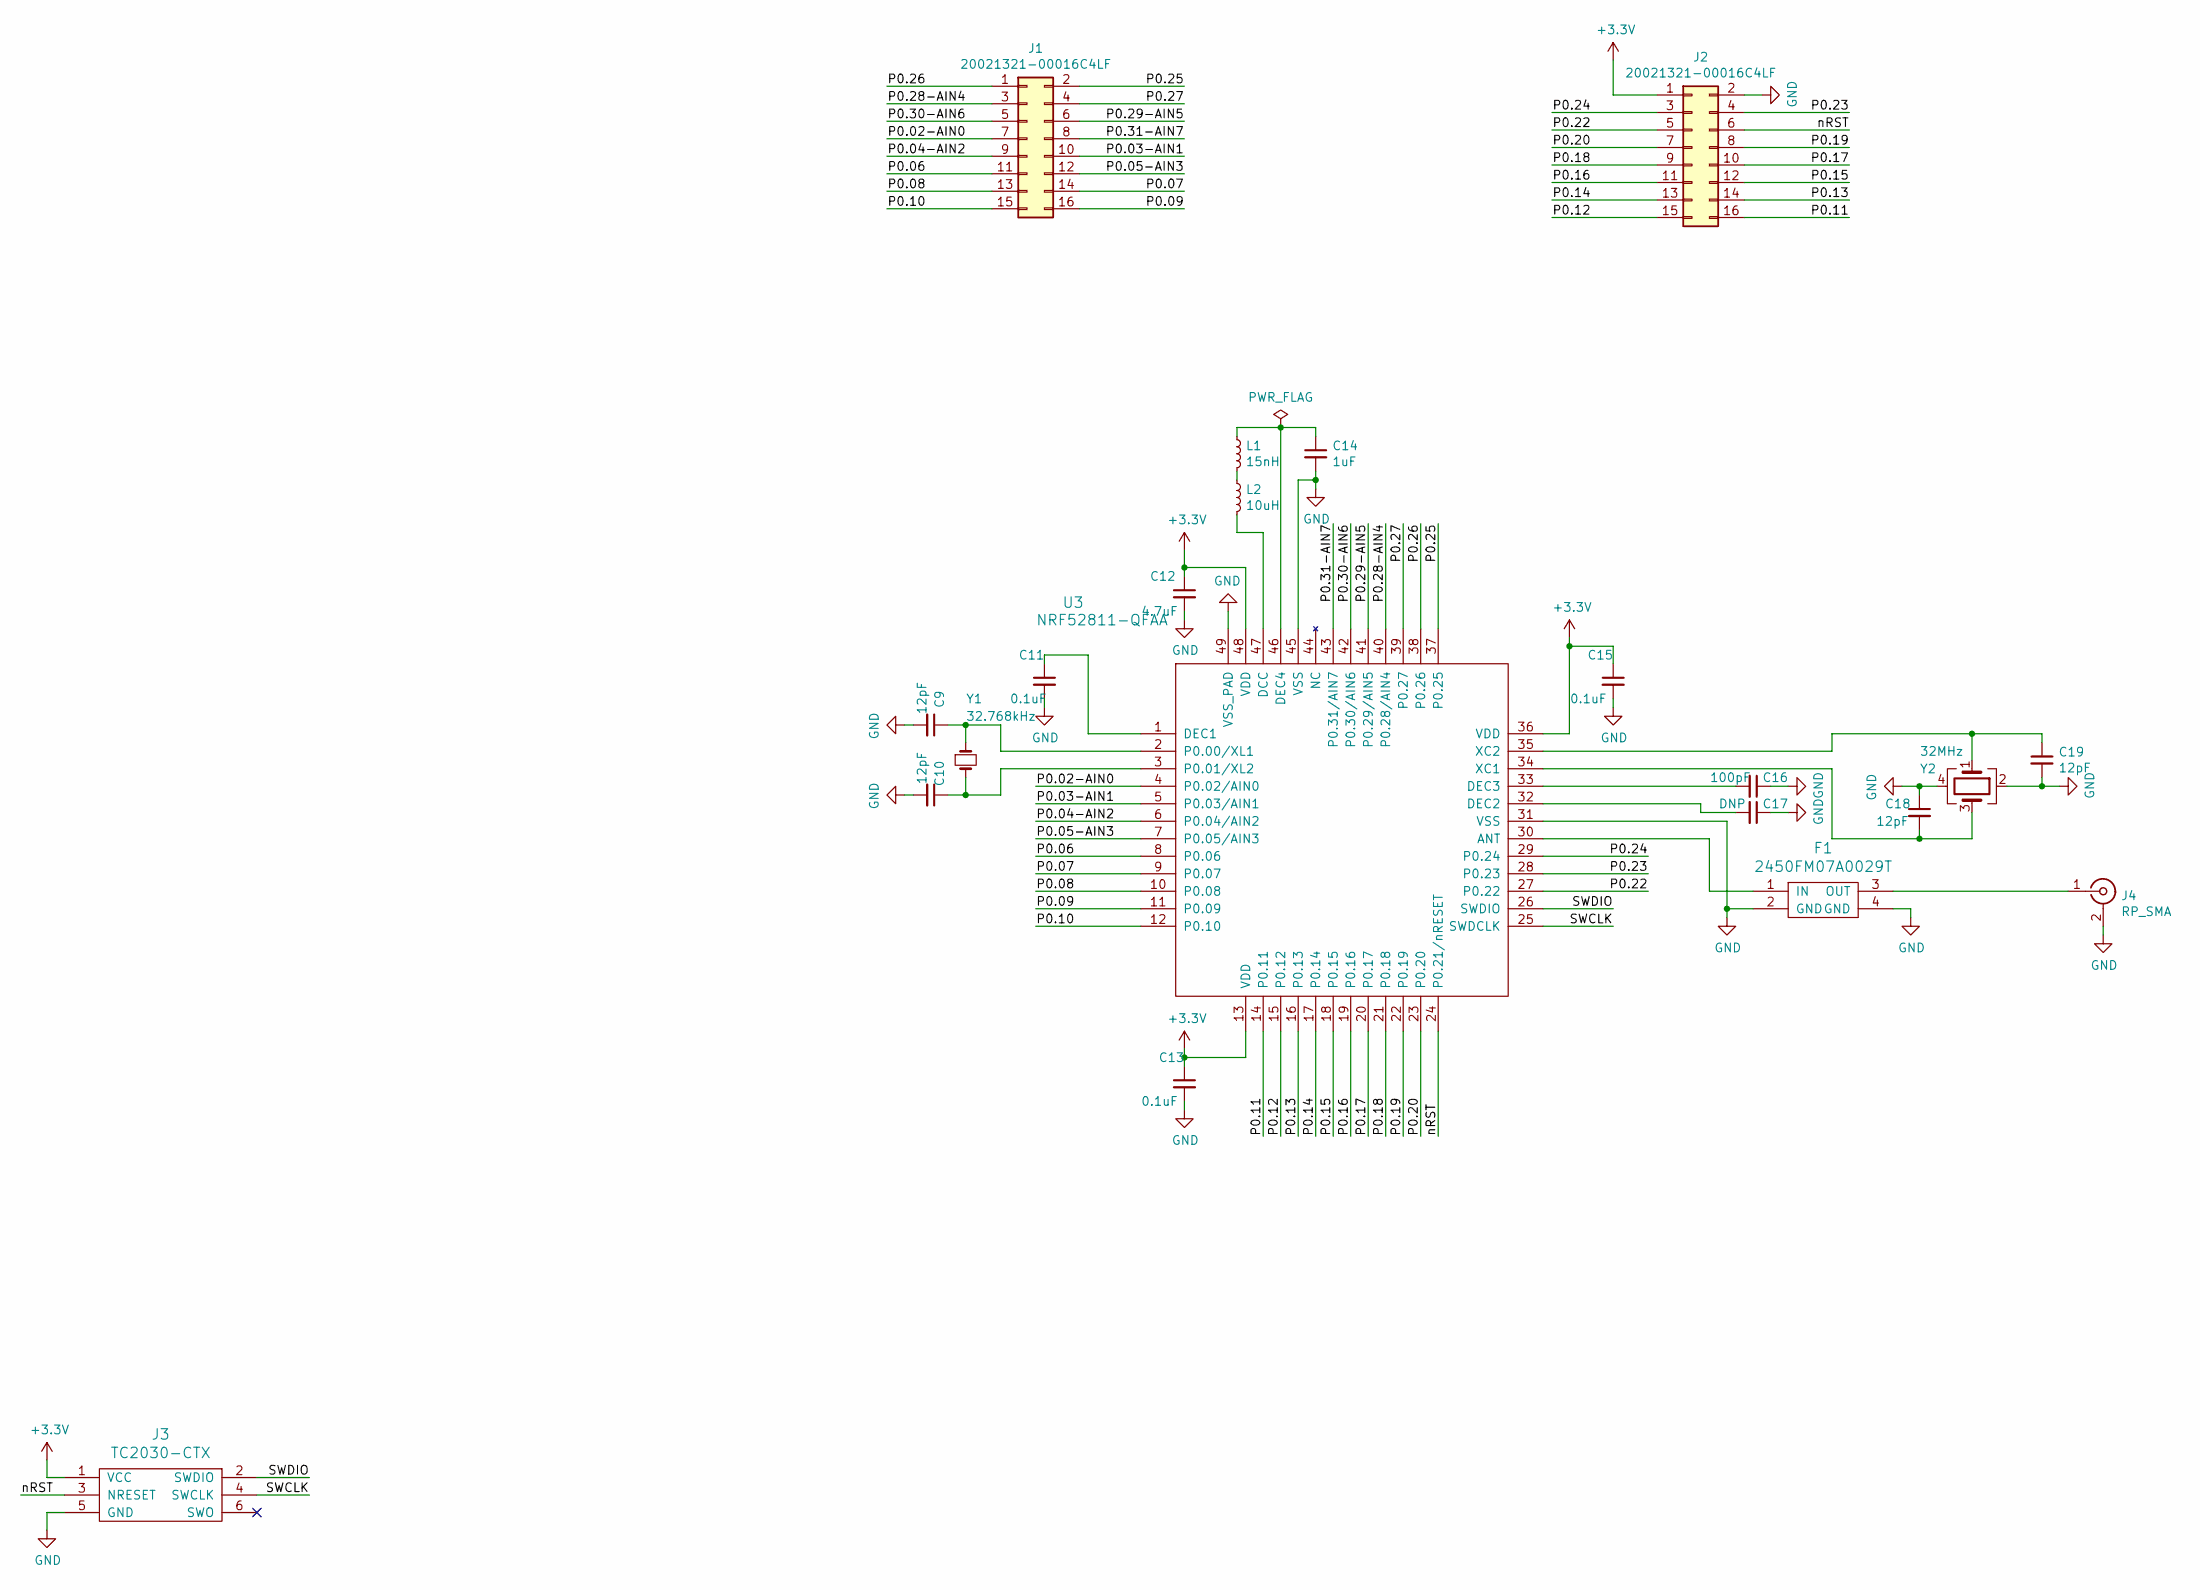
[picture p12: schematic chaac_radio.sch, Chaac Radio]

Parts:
C9, C10, C18, C19: 12pF; C_0402_1005Metric; MPN C0402C120J5GACTU
C11, C13, C15: 0.1uF; C_0402_1005Metric; MPN GRM155R61A104KA01D
C12: 4.7uF; C_0402_1005Metric; MPN GRM155R60J475ME47D
C14: 1uF; C_0402_1005Metric; MPN CC0402KRX5R5BB105
C16: 100pF; C_0402_1005Metric; MPN UMK105CG101JV-F
C17: DNP; C_0402_1005Metric
F1: 2450FM07A0029T; MPN 2450FM07A0029T
J1, J2: 20021321-00016C4LF; MPN 20021321-00016C4LF
J3: TC2030-CTX; TC2030-NL
J4: RP_SMA; MOLEX-0734150963; MPN CONREVSMA003.062
L1: 15nH; L_0402_1005Metric; MPN HK100515NJ-T‎
L2: 10uH; L_0603_1608Metric; MPN ‎LQM18FN100M00D‎
U3: NRF52811-QFAA; QFN-48-1EP_6x6mm_P0.4mm_EP4.6x4.6mm; MPN ‎NRF52811-QFAA-R‎
Y1: 32.768kHz; Crystal_SMD_3215-2Pin_3.2x1.5mm; MPN FC-135 32.7680KA-AC0
Y2: 32MHz; Crystal_SMD_2016-4Pin_2.0x1.6mm; MPN CX2016DB32000D0FLJCC

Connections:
+3V3: C12.1, C13.1, C15.1, J2.1, J3.1 (VCC), U3.13 (VDD), U3.36 (VDD), U3.48 (VDD)
/P0.02-AIN0: J1.7, U3.4 (P0.02/AIN0)
/P0.03-AIN1: J1.10, U3.5 (P0.03/AIN1)
/P0.04-AIN2: J1.9, U3.6 (P0.04/AIN2)
/P0.05-AIN3: J1.12, U3.7 (P0.05/AIN3)
/P0.06: J1.11, U3.8 (P0.06)
/P0.07: J1.14, U3.9 (P0.07)
/P0.08: J1.13, U3.10 (P0.08)
/P0.09: J1.16, U3.11 (P0.09)
/P0.10: J1.15, U3.12 (P0.10)
/P0.11: J2.16, U3.14 (P0.11)
/P0.12: J2.15, U3.15 (P0.12)
/P0.13: J2.14, U3.16 (P0.13)
/P0.14: J2.13, U3.17 (P0.14)
/P0.15: J2.12, U3.18 (P0.15)
/P0.16: J2.11, U3.19 (P0.16)
/P0.17: J2.10, U3.20 (P0.17)
/P0.18: J2.9, U3.21 (P0.18)
/P0.19: J2.8, U3.22 (P0.19)
/P0.20: J2.7, U3.23 (P0.20)
/P0.22: J2.5, U3.27 (P0.22)
/P0.23: J2.4, U3.28 (P0.23)
/P0.24: J2.3, U3.29 (P0.24)
/P0.25: J1.2, U3.37 (P0.25)
/P0.26: J1.1, U3.38 (P0.26)
/P0.27: J1.4, U3.39 (P0.27)
/P0.28-AIN4: J1.3, U3.40 (P0.28/AIN4)
/P0.29-AIN5: J1.6, U3.41 (P0.29/AIN5)
/P0.30-AIN6: J1.5, U3.42 (P0.30/AIN6)
/P0.31-AIN7: J1.8, U3.43 (P0.31/AIN7)
/SWCLK: J3.4 (SWCLK), U3.25 (SWDCLK)
/SWDIO: J3.2 (SWDIO), U3.26 (SWDIO)
/nRST: J2.6, J3.3 (NRESET), U3.24 (P0.21/nRESET)
GND: C9.2, C10.2, C11.2, C12.2, C13.2, C14.2, C15.2, C16.1, C17.1, C18.1, C19.2, F1.2 (GND), F1.4 (GND), J2.2, J3.5 (GND), J4.2 (Ext), U3.31 (VSS), U3.45 (VSS), U3.49 (VSS_PAD), Y2.2, Y2.4
unnamed: C9.1, U3.2 (P0.00/XL1), Y1.1
unnamed: C10.1, U3.3 (P0.01/XL2), Y1.2
unnamed: C11.1, U3.1 (DEC1)
unnamed: C14.1, L1.1, U3.46 (DEC4)
unnamed: C16.2, U3.33 (DEC3)
unnamed: C17.2, U3.32 (DEC2)
unnamed: C18.2, U3.34 (XC1), Y2.3
unnamed: C19.1, U3.35 (XC2), Y2.1
unnamed: F1.1 (IN), U3.30 (ANT)
unnamed: F1.3 (OUT), J4.1 (In)
unnamed: L1.2, L2.1
unnamed: L2.2, U3.47 (DCC)



Board: 4 copper layers, 40.0 x 20.0 mm, 21 parts (2 on the bottom side), 46 nets.

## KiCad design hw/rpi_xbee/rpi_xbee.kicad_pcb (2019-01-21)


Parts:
C1: 1uF; C_0603_1608Metric
C2: 8.2pF; C_0603_1608Metric
C3: 10uF; C_0603_1608Metric
J1: RPi; PinSocket_2x05_P2.54mm_Vertical
R1: 10k; R_0603_1608Metric
U1: XBEE_S2C; XBEE_S2C_TH

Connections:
+3V3: C1.1, C2.1, C3.1, J1.1, U1.1 (VCC)
/PI_RX: J1.10, U1.2 (DOUT)
/PI_TX: J1.8, U1.3 (DIN)
GND: C1.2, C2.2, C3.2, J1.6, J1.9, R1.2, U1.10 (GND)
unnamed: R1.1, U1.5 (nRST)


Board: 2 copper layers, 25.4 x 22.9 mm, 6 parts (1 on the bottom side), 5 nets.

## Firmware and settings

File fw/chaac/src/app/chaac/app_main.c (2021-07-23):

#include "stm32l4xx_hal.h"
#include "FreeRTOS.h"
#include "task.h"
#include "main.h"
// #include "printf.h"
#include "adc.h"
#include "chaac_packet.h"
#include "debug.h"
#include "dps368.h"
#include "FreeRTOSLPM.h"
#include "gpio.h"
#include "i2c.h"
#include "info.h"
#include "IOAdc.h"
#include "IOI2c.h"
#include "iwdg.h"
#include "loraRadio.h"
#include "memfault/components.h"
#include "memfault/core/data_packetizer.h"
#include "packet.h"
#include "radio.h"
#include "sensor.h"
#include "sht3x.h"
#include "spi.h"
#include "windrain.h"
#include <string.h>

static weather_packet_v1p1_t packet;

extern __IO uint32_t uwTick;
volatile bool useFreeRTOSTick = false;

uint32_t HAL_GetTick(void) {
    if(useFreeRTOSTick) {
        return xTaskGetTickCount();
    } else {
        return uwTick;
    }
}

void HAL_Delay(uint32_t delay) {
    if(useFreeRTOSTick) {
        vTaskDelay(delay);
    } else {
        uint32_t tickstart = HAL_GetTick();
        uint32_t wait = delay;

        /* Add a period to guaranty minimum wait */
        if (wait < HAL_MAX_DELAY) {
            wait += (uint32_t)uwTickFreq;
        }

        while ((HAL_GetTick() - tickstart) < wait) {};
    }
}


loraMode_t loraRxCallback(uint8_t *buff, size_t len, int16_t rssi, int8_t snr){
    (void)snr;
    (void)rssi;

    // Check packet CRC
    if(packetIsValid(buff, len)) {
        packet_header_t *packetHeader = (packet_header_t *)buff;
        chaac_header_t *chaacPacketHeader = (chaac_header_t *)&packetHeader[1];
        if((chaacPacketHeader->uid == getHWID()) &&
            (chaacPacketHeader->type == PACKET_TYPE_RESET)) {
            NVIC_SystemReset();
        }
    }

    return RADIO_MODE_SLEEP;
}

loraMode_t loraRxTimeoutCallback() {
    return RADIO_MODE_SLEEP;
}

loraMode_t loraRxErrorCallback() {
    return RADIO_MODE_SLEEP;
}

loraMode_t loraTxCallback() {
    loraRadioSetRxTimeout(500);
    return RADIO_MODE_RX;
}

loraMode_t loraTxTimeoutCallback() {
    return RADIO_MODE_SLEEP;
}

static uint32_t prvAdcGetSampleMv(uint32_t ulChannel) {
    int32_t lResult = 0;

    ADC_ChannelConfTypeDef xConfig = {0};

    xConfig.Rank = ADC_REGULAR_RANK_1;
    xConfig.SamplingTime = ADC_SAMPLETIME_2CYCLES_5;
    xConfig.SingleDiff = ADC_SINGLE_ENDED;
    xConfig.OffsetNumber = ADC_OFFSET_NONE;
    xConfig.Offset = 0;

    xConfig.Channel = ulChannel;
    xIOAdcChannelConfig(&hadc1, &xConfig);

    xIOAdcReadMv(&hadc1, &lResult);
    return ((uint32_t)lResult);
}


static void showError(uint32_t error) {
    for(uint32_t x = 0; x < 20; x++) {
        LL_GPIO_SetOutputPin(LED1_GPIO_Port, LED1_Pin);
        vTaskDelay(25);
        LL_GPIO_ResetOutputPin(LED1_GPIO_Port, LED1_Pin);
        vTaskDelay(25);
    }

    vTaskDelay(475);

    for(uint32_t x = 0; x < error; x++) {
        LL_GPIO_SetOutputPin(LED1_GPIO_Port, LED1_Pin);
        vTaskDelay(250);
        LL_GPIO_ResetOutputPin(LED1_GPIO_Port, LED1_Pin);
        vTaskDelay(250);
    }

    vTaskDelay(250);

    for(uint32_t x = 0; x < 20; x++) {
        LL_GPIO_SetOutputPin(LED1_GPIO_Port, LED1_Pin);
        vTaskDelay(25);
        LL_GPIO_ResetOutputPin(LED1_GPIO_Port, LED1_Pin);
        vTaskDelay(25);
    }
}

void packetTxFn(int16_t len, void* data) {
    loraRadioSend((uint8_t *)data, len);
}

int32_t winGetDirMv() {
    int32_t mv = 0;

    // Enable sensor power rail
    LL_GPIO_ResetOutputPin(SNS_3V3_EN_GPIO_Port, SNS_3V3_EN_Pin);

    // Wait for power to make it out and back for a good measurement
    vTaskDelay(25);

    xIOAdcInit(&hadc1);
    mv = prvAdcGetSampleMv(ADC_CHANNEL_5);
    xIOAdcDeInit(&hadc1);

    // Disable sensor power rail
    LL_GPIO_SetOutputPin(SNS_3V3_EN_GPIO_Port, SNS_3V3_EN_Pin);

    return mv;
}

static windDirCfg_t windCfg = {&winGetDirMv};

static sensor_t shtTemperature;
static sensor_t shtHumidity;
static sensor_t dpsPressure;
static sensor_t dpsTemperature;
static sensor_t vBatt;
static sensor_t vSolar;

#define MEMFAULT_DATA_MAX_LEN 256
static void sendMemfaultData() {
    uint8_t *buf = pvPortMalloc(MEMFAULT_DATA_MAX_LEN);
    memfault_packet_t *packet = (memfault_packet_t *)buf;
    packet->header.uid = getHWID();
    packet->header.type = PACKET_TYPE_MEMFAULT;
    size_t buf_len = MEMFAULT_DATA_MAX_LEN - sizeof(memfault_packet_t);
    if(memfault_packetizer_get_chunk(&packet[1], &buf_len)) {
        packet->len = buf_len;
        packetTx(buf_len + sizeof(memfault_packet_t), buf, packetTxFn);
    }
    vPortFree(buf);
}

static void mainTask( void *pvParameters ) {
    (void)pvParameters;

    LL_GPIO_ResetOutputPin(RADIO_NRST_GPIO_Port, RADIO_NRST_Pin);

    windRainInit(&windCfg);

    while(!isRadioReady()) {
        vTaskDelay(100);
    }

    sendMemfaultData();

    packet.header.type = PACKET_TYPE_WEATHER_V1P1;
    packet.header.uid = getHWID();
    packet.sample = 0;

    for(;;) {
        vTaskDelay(60 * 1000);

        float fVal;

        if(sensorGetAvg(&shtTemperature, &fVal)) {
            packet.temperature = (int16_t)fVal;
            sensorClearSamples(&shtTemperature);
        } else {
            packet.temperature = -27300;
        }

        if(sensorGetAvg(&shtHumidity, &fVal)) {
            packet.humidity = (uint16_t)fVal;
            sensorClearSamples(&shtHumidity);
        } else {
            packet.humidity = 0;
        }

        if(sensorGetAvg(&dpsPressure, &fVal)) {
            packet.pressure = (uint16_t)fVal;
            sensorClearSamples(&dpsPressure);
        } else {
            packet.pressure = INT16_MIN;
        }

        if(sensorGetAvg(&dpsTemperature, &fVal)) {
            packet.alt_temperature = (int16_t)(fVal * 100);
            sensorClearSamples(&dpsTemperature);
        } else {
            packet.alt_temperature = -27300;
        }

        if(sensorGetAvg(&vBatt, &fVal)) {
            packet.battery = (uint16_t)fVal;
            sensorClearSamples(&vBatt);
        } else {
            packet.battery = 0;
        }

        if(sensorGetAvg(&vSolar, &fVal)) {
            packet.solar_panel = (uint16_t)fVal;
            sensorClearSamples(&vSolar);
        } else {
            packet.solar_panel = 0;
        }

        packet.rain = windRainGetRain()/2794;

        // Store wind speed in kph * 100
        packet.wind_speed = windRainGetSpeed()/10;
        packet.gust_speed = windRainGetGust()/10;

        packet.wind_dir_deg = windRainGetAvgDirDegrees();


        windRainClearRain();

        packetTx(sizeof(packet), &packet, packetTxFn);

        packet.sample++;
    }
}

static void sensorsTask( void *pvParameters ) {
    (void)pvParameters;

    LL_GPIO_ResetOutputPin(RADIO_NRST_GPIO_Port, RADIO_NRST_Pin);

    xIOI2cInit(&hi2c1);

    uint32_t ulRval = ulSht3xInit(&hi2c1, SHT3x_ADDR);
    if(ulRval) {
        showError(1);
    }

    ulRval = dps368_init(&hi2c1);
    if(ulRval) {
        showError(2);
    }

    xIOI2cDeInit(&hi2c1);

    for(;;) {

        xIOI2cInit(&hi2c1);

        int16_t sTemperature, sHumidity;
        ulRval = ulSht3xRead(&hi2c1, SHT3x_ADDR, &sTemperature, &sHumidity);
        if(ulRval == 0) {
            sensorAddSample(&shtTemperature, sTemperature);
            sensorAddSample(&shtHumidity, sHumidity);
        }

        float fTemperature, fPressure;
        ulRval = dps368_measure_temp_once(&fTemperature);
        if (ulRval == 0) {
            sensorAddSample(&dpsTemperature, fTemperature);
        } else {
            // printf("Error reading DPS368 Temperature (%d)\n", ulRval);
        }
        ulRval = dps368_measure_pressure_once(&fPressure);
        if (ulRval == 0) {
            sensorAddSample(&dpsPressure, (fPressure - 100000.0));
        } else  {
            // printf("Error reading DPS368 Pressure (%d)\n", ulRval);
        }
        xIOI2cDeInit(&hi2c1);

        xIOAdcInit(&hadc1);
        sensorAddSample(&vBatt, prvAdcGetSampleMv(ADC_CHANNEL_7) * 2);
        sensorAddSample(&vSolar, prvAdcGetSampleMv(ADC_CHANNEL_6) * 2);
        xIOAdcDeInit(&hadc1);

        vTaskDelay(1000);
    }
}

extern SPI_HandleTypeDef hspi1;

void spiSetupFn() {
    MX_SPI1_Init();
}

void spiTeardownFn() {
    HAL_SPI_DeInit(&hspi1);
}

static loraRadioConfig_t loraConfig = {
    .startMode = RADIO_MODE_SLEEP,
    .spiSetupFn = spiSetupFn,
    .spiTeardownFn = spiTeardownFn,
    .rxCb = loraRxCallback,
    .txCb = loraTxCallback,
    .rxTimeoutCb = loraRxTimeoutCallback,
    .txTimeoutCb = loraRxErrorCallback,
    .rxErrorCb = NULL,
};

static void watchdogTask( void *pvParameters ) {
    (void)pvParameters;

    for(;;) {
        HAL_IWDG_Refresh(&hiwdg);
        vTaskDelay(10);
    }
}

int main(void) {
    HAL_Init();

    SystemClock_Config();

    MX_GPIO_Init();
    MX_IWDG_Init();

    memfault_platform_boot();

    BaseType_t xRval = xTaskCreate(
            mainTask,
            "main",
            512,
            NULL,
            3,
            NULL);

    configASSERT(xRval == pdTRUE);

    loraRadioInit(&loraConfig);

    xRval = xTaskCreate(
        sensorsTask,
        "sensors",
        512,
        NULL,
        2,
        NULL);

    configASSERT(xRval == pdTRUE);

    xRval = xTaskCreate(
        watchdogTask,
        "iwdg",
        128,
        NULL,
        0,
        NULL);

    configASSERT(xRval == pdTRUE);

    lpmInit();
    lpmEnable();

    useFreeRTOSTick = true;
    HAL_SuspendTick();

    vTaskStartScheduler();

    __builtin_unreachable();
}

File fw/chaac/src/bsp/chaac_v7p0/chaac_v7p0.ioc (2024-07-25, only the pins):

Mcu.UserName=STM32L412KBTx
PA0-CK_IN.GPIO_Label=BATT
PA0-CK_IN.Signal=ADCx_IN5
PA1.GPIO_Label=SOLAR
PA1.Signal=ADCx_IN6
PA11.Signal=USB_DM
PA12.Signal=USB_DP
PA2.Signal=LPUART1_TX
PA3.Signal=LPUART1_RX
PA4.GPIO_Label=RADIO_CS
PA4.Signal=GPIO_Output
PA5.Signal=SPI1_SCK
PA6.Signal=SPI1_MISO
PA7.Signal=SPI1_MOSI
PA8.GPIO_Label=RADIO_DIO1
PA8.Signal=GPXTI8
PA9.GPIO_Label=RADIO_DIO2
PA9.Signal=GPIO_Input
PB0.GPIO_Label=RS232_EN
PB0.Signal=GPIO_Output
PB1.GPIO_Label=NINVALID
PB1.Signal=GPIO_Input
PB5.GPIO_Label=RADIO_TXEN
PB5.Signal=GPIO_Output
PB6.GPIO_Label=RADIO_NRST
PB6.Signal=GPIO_Output
PB7.GPIO_Label=RADIO_BUSY
PB7.Signal=GPIO_Input

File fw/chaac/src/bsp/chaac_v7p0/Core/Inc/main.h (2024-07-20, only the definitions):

#define BATT_Pin LL_GPIO_PIN_0
#define BATT_GPIO_Port GPIOA
#define SOLAR_Pin LL_GPIO_PIN_1
#define SOLAR_GPIO_Port GPIOA
#define RADIO_CS_Pin LL_GPIO_PIN_4
#define RADIO_CS_GPIO_Port GPIOA
#define RS232_EN_Pin LL_GPIO_PIN_0
#define RS232_EN_GPIO_Port GPIOB
#define NINVALID_Pin LL_GPIO_PIN_1
#define NINVALID_GPIO_Port GPIOB
#define RADIO_DIO1_Pin LL_GPIO_PIN_8
#define RADIO_DIO1_GPIO_Port GPIOA
#define RADIO_DIO1_EXTI_IRQn EXTI9_5_IRQn
#define RADIO_DIO2_Pin LL_GPIO_PIN_9
#define RADIO_DIO2_GPIO_Port GPIOA
#define LED2_Pin LL_GPIO_PIN_15
#define LED2_GPIO_Port GPIOA
#define LED1_Pin LL_GPIO_PIN_3
#define LED1_GPIO_Port GPIOB
#define RADIO_RXEN_Pin LL_GPIO_PIN_4
#define RADIO_RXEN_GPIO_Port GPIOB
#define RADIO_TXEN_Pin LL_GPIO_PIN_5
#define RADIO_TXEN_GPIO_Port GPIOB
#define RADIO_NRST_Pin LL_GPIO_PIN_6
#define RADIO_NRST_GPIO_Port GPIOB
#define RADIO_BUSY_Pin LL_GPIO_PIN_7
#define RADIO_BUSY_GPIO_Port GPIOB

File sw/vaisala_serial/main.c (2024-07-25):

#include <errno.h>
#include <fcntl.h>
#include <stdint.h>
#include <stdio.h>
#include <stdlib.h>
#include <string.h>
#include <termios.h>
#include <unistd.h>

#include "vaisala.h"

int main(int argc, char **argv) {
  if (argc < 2) {
    printf("Usage: vaisala_serial port baudrate\n");
  }

  uint32_t baud_rate = strtoul(argv[2], NULL, 10);

  int serial_port = open(argv[1], O_RDWR);
  if (serial_port < 0) {
    printf("Error %i opening serial port: %s\n", errno, strerror(errno));
    return -1;
  }

  // Create new termios struct, we call it 'tty' for convention
  // No need for "= {0}" at the end as we'll immediately write the existing
  // config to this struct
  struct termios tty;

  // Read in existing settings, and handle any error
  // NOTE: This is important! POSIX states that the struct passed to tcsetattr()
  // must have been initialized with a call to tcgetattr() overwise behaviour
  // is undefined
  if (tcgetattr(serial_port, &tty) != 0) {
    printf("Error %d from tcgetattr: %s\n", errno, strerror(errno));
  }

  tty.c_cflag |= CS8;  // 8 bits per byte (most common)

  tty.c_cflag &= ~PARENB;  // Clear parity bit, disabling parity (most common)

  tty.c_cflag &= ~CSTOPB;  // Clear stop field, only one stop bit used in
                           // communication (most common)

  tty.c_cflag &=
      ~CRTSCTS;  // Disable RTS/CTS hardware flow control (most common)

  tty.c_cflag |=
      CREAD | CLOCAL;  // Turn on READ & ignore ctrl lines (CLOCAL = 1)

  tty.c_lflag &= ~ICANON;  // Disable canonical mode
  tty.c_lflag &= ~ECHO;    // Disable echo
  tty.c_lflag &= ~ECHOE;   // Disable erasure
  tty.c_lflag &= ~ECHONL;  // Disable new-line echo

  tty.c_lflag &= ~ISIG;  // Disable interpretation of INTR, QUIT and SUSP
  tty.c_iflag &= ~(IXON | IXOFF | IXANY);  // Turn off s/w flow ctrl
  tty.c_iflag &= ~(IGNBRK | BRKINT | PARMRK | ISTRIP | INLCR | IGNCR |
                   ICRNL);  // Disable any special handling of received bytes
  tty.c_oflag &= ~OPOST;    // Prevent special interpretation of output bytes
                            // (e.g. newline chars)
  tty.c_oflag &=
      ~ONLCR;  // Prevent conversion of newline to carriage return/line feed

  tty.c_cc[VTIME] = 0;  // Wait forever
  tty.c_cc[VMIN] = 1;   // Wait for at least 1 character before returning

  cfsetispeed(&tty, baud_rate);
  cfsetospeed(&tty, baud_rate);

  // Save tty settings, also checking for error
  if (tcsetattr(serial_port, TCSANOW, &tty) != 0) {
    printf("Error %i from tcsetattr: %s\n", errno, strerror(errno));
  }

  char buff[1024];
  uint32_t idx = 0;

  while (1) {
    int rval = read(serial_port, &buff[idx++], 1);
    if (rval == 0) {
      printf(".");
      continue;
    } else if (rval < 0) {
      printf("read error %d\n", rval);
      break;
    }

    // No overflows please
    if (idx >= sizeof(buff)) {
      idx = 0;
      continue;
    }

    if (buff[idx - 1] == '\n') {
      // Buffer is too short (Should be at least 1 char + CRC(3) + CLRF(2))
      if (idx <= (VCRC_LEN + 3)) {
        idx = 0;
        continue;
      }

      // Remove CRLF
      idx -= 2;

      vaisala_parse_msg(buff, idx);

      idx = 0;
    }
  }

  close(serial_port);
}

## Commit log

2018-12-27 First commit of chaac!
    Server seems to be working on the raspberry pi :D
2019-01-10 Initial commit of Chaac FW
    [nucleo-l432kc_openocd.cfg]
2019-01-10 Adding chaac hw
    [chaac.kicad_pcb, chaac.sch]
2019-01-12 Removed no-connect and updated hw gitignore
    [chaac.sch]
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2019-01-12 Fix uarts and start using xbee in low power mode :D
    [main.c]
2019-01-12 Rename bsp to match actual board
    [nucleo-l432kc_openocd.cfg]
2019-01-12 Fix xbee uart pin
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2019-01-19 Fix BSP timers and enable cpu_timer
2019-01-19 Fix bootloader uart (default to xbee)
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2019-01-20 Fix light sensor range and minor comment
    [main.c]
2019-01-20 Updated Chaac HW to v1.1
    Added gate for controlling power to wind direction sensor and light sensor.
    (This should allow for power gating for lower power consumption)
    Removed all GPS stuff (won't be using it this time)
    Removed fan driver. (also won't be using it)
    Added pull down resistors on xbee enable and boot0.
    Fixed battery charger bug (PROG1 and PROG2 were flipped)
    Added 1k resistor to therm pin
    Flipped wind/rain connector location for simpler routing
    [chaac.kicad_pcb, chaac.sch]
2019-01-21 Added rpi xbee hat
    [rpi_xbee.kicad_pcb, rpi_xbee.sch]
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2019-01-29 Did layout/schematic for chaac v1.2
    Added extra led, boot button, and sense resistors for solar panel voltage
    [chaac.kicad_pcb, chaac.sch]
2019-01-29 Set unrealistic values during error
    [main.c]
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2019-02-08 Now change xbee uart baud to 57600
    Turns out 115200 is OK as far as baud rate, clock speed, and downsampling
    The problem is the 1kHz systick happening during an rx, which causes
    some bytes to go unprocessed
    [main.c]
2019-02-08 Adding workaround for raspberry pi serial flush
    [update.py]
2019-02-08 Looks like flushOutput might be the actual problem...
    [update.py]
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2019-02-09 Bootloader update!
    If the user uses the boot button during reset, the debug UART
    will be used for the bootloader.
    If the boot pin is not asserted during boot, the xbee uart will be
    used instead.
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2019-05-22 Swapping processor for NRF52811
    [chaac.sch]
2019-05-23 Released chaac v2.0 to JLCPCB
    [chaac.kicad_pcb, chaac.sch, chaac.step]
2019-05-24 Don't track step file for now
    [chaac.step]
2019-05-24 Start working on nrf52811_usb dongle
    [nrf52811_usb.kicad_pcb, nrf52811_usb.sch]
2019-05-25 Released nrf52811_usb to oshpark :D
    [nrf52811_usb.kicad_pcb, nrf52811_usb.sch]
2019-05-25 Updated BOM for nrf52811_usb
    [nrf52811_usb.sch]
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2019-05-31 Fix jlink.py script to take in both hex and decimal address/len
    [jlink.py]
2019-06-01 Started schematic/layout on nrf52811_breakout
    [nrf52811_breakout.kicad_pcb, nrf52811_breakout.sch]
2019-06-02 Finished? layout for chaac radio v1.0?
    [nrf52811_breakout.kicad_pcb, nrf52811_breakout.sch]
2019-06-02 renamed nrf51822_breakout to chaac_radio
    Fixed up some via alignment and stitching
    [chaac_radio.kicad_pcb, chaac_radio.sch, nrf52811_breakout.kicad_pcb]
2019-06-02 Progress with chaac base
    [chaac.kicad_pcb, chaac.sch, chaac_radio.kicad_pcb]
2019-06-02 Done routing chaac v3.0 base board?
    [chaac.kicad_pcb, chaac.sch]
2019-06-02 re-annotated schematic/board
    [chaac.kicad_pcb, chaac.sch]
2019-06-02 Fixed DRC errors and added url
    [chaac.kicad_pcb]
2019-06-02 Updated bom and matched trace for JLCPCB impedance control
    [chaac_radio.kicad_pcb, chaac_radio.sch]
2019-06-02 Removed chaac radio from chaac and used 2 connectors
    Ordered chaac radio from JLCPCB
    Ordered chaac from oshpark
    [chaac.kicad_pcb]
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2019-06-09 Forgot to commit chaac schematic! :-/
    [chaac.sch]
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2019-06-15 Fix hw version definition and rain pin on chaacv3
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2019-09-22 Released chaac v3.1 to OSHPark
    Moved NRF52 back into chaac pcb.
    Removed external T/H connector, switched to BME280 for temp, humidity,
    and pressure sensing.
    Using RP-SMA connector for this version.
    [chaac.kicad_pcb, chaac.sch]
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2019-10-02 minor fixes to bme280 driver. It compiles now :D Still untested
2019-10-04 Fixed hw version in bsp and change beacon magic to work again
    [main.c]
2019-10-06 Fixed BME280 code so it enables humidity measurements...
    [main.c]
2019-10-13 Created rpi_nrf52811 v1.0 and released to oshpark
    [rpi_nrf52811.kicad_pcb, rpi_nrf52811.sch]
2019-11-01 Fix data de-duplication bug
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2020-02-20 Fix bug with new devices
2020-06-10 Adding nrf5281x_usb_lora
    [nrf5281x_usb_lora.kicad_pcb, nrf5281x_usb_lora.sch]
2020-06-15 Started chaac v4.0 Schematic + layout
    [chaac.kicad_pcb, chaac.sch]
2020-06-16 Finished chaac v4.0!
    [chaac.kicad_pcb, chaac.sch]
2020-06-16 Just kidding. Fixed chaac v4.0 outline
    [chaac.kicad_pcb]
2020-06-21 Fix part number for U2
    [nrf5281x_usb_lora.sch]
2020-06-21 Fix blinky_usb.
    console_printf was crashing because the task stack was too small!
    [main.c]
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2020-06-24 Update components for chaac schematic
    [chaac.sch]
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2020-07-19 Changing vbat sense resistors from 100k to 1Mohm
    [chaac.sch]
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2020-07-28 Switch BMP280 to forced mode
    Updated led to blink on transmit, not sample.
    Updated error values for temperature and pressure
    [main.c]
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2020-08-17 Fixing collision between CS and LED1 pin
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2020-08-23 Adding changes for lora test (not working)
    [main.c]
2020-08-24 Adding chaac v5.0
    [chaac.kicad_pcb, chaac.sch]
2020-09-01 Updated nrf5281x_usb_lora to be smaller
    [nrf5281x_usb_lora.kicad_pcb, nrf5281x_usb_lora.sch]
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2020-09-20 Update windrain driver to work with chaac v5
    Fix windraincalc script
    [winddircalc.py]
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2020-10-04 Fix minor setup bug and update lora_mqtt_client
    [lora_mqtt_client.py]
2020-10-16 Fixed chaac lora pressure!
    Value was being sent as unsigned int 16, if pressure was below
    1000.00 hPa, it would report inaccurately.
    Noticed this because Sunbright is above sea level and was reading
    values such as 1619.68 hPa instead of 960something.
2020-10-17 Update downsample to fix pressure data
    [downsample.py]
2020-10-17 Adding sketchy sample detection
    There seem to be issues with the LoRa radios.
    Sometimes data arrives a bit wrong. I'm guessing
    the data might be getting corrupted.
    Until I can add CRC to fw and update field units,
    I'll try to detect "sketchy" samples and save them
    in a separate table for later analysis.
2020-11-27 Re-did layout for chaac v6
    [chaac.kicad_pcb, chaac.sch]
2020-12-05 Cleaned up chaac layout
    [chaac.kicad_pcb, chaac.sch]
2020-12-06 Finished and released chaac v6
    [chaac.kicad_pcb, chaac.sch]
2020-12-20 Update part numbers?
    [chaac.sch]
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2020-12-25 Make sure device is reset before flashing
    This makes sure that we can flash even if device is in WFI
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2020-12-28 Added support for multiple BSP/APP/Debugger
    For example:
    cmake .. -DCMAKE_TOOLCHAIN_FILE=../cmake/toolchains/cross/STM32L412KBUx.cmake -DCMAKE_BUILD_TYPE=Debug -DAPP=test -DBSP=chaac_v6p0 -DDEBUGGER=bmp
    or
    cmake .. -DCMAKE_TOOLCHAIN_FILE=../cmake/toolchains/cross/STM32L412KBUx.cmake -DCMAKE_BUILD_TYPE=Debug -DAPP=radio_rx -DBSP=radio_test -DDEBUGGER=stlink
    [st_nucleo_l4.cfg]
2020-12-29 Whoops. Fixed debug printf
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2020-12-31 Make sure we can flash parts in stop mode
    [st_nucleo_l4.cfg]
2020-12-31 Make sure stlink can debug while in low power mode (will reset the target)
2020-12-31 Added support for multiple STLink debuggers
    Following this guide:
    https://www.bergzand.net/programming-with-multiple-st-link-programmers.html
    To get the serial number, use `udevadm info /dev/ttyACM2 | grep ID_SERIAL_SHORT` or `lsusb -v -d 0483:374b | grep iSerial` (on the appropriate device, of course)
    To flash/debug a specific device, do `STLINK_SERIAL=001F00463438510C34313939 make flash`
    [st_nucleo_l4.cfg, stlink-mod.cfg]
2021-01-09 Forgot to commit some changes to pcb
    [chaac.kicad_pcb]
2021-01-24 Inidialize usb cdc and add static malloc fix
    For more info, see:
    * https://community.st.com/s/question/0D50X0000BCNOz7/why-does-the-hal-usb-cdc-driver-call-malloc-in-an-isr-context-again
    * https://www.st.com/resource/en/user_manual/dm00108129-stm32cube-usb-device-library-stmicroelectronics.pdf
    [app_main.c]
2021-01-24 Got very basic usb tx working
    [st_nucleo_l4.cfg]
2021-03-06 Committing chaac v6.1 files I forgot to :(
    [chaac.kicad_pcb, chaac.sch]
2021-03-28 Use the correct init/deinit functions for I2C and ADC
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2021-03-28 Start disabling interfaces when not in use
    Also added error code blinky thing
    [app_main.c]
2021-05-16 Adding antenna test board (ordered from oshpark)
    [antenna-test.kicad_pcb, antenna-test.sch]
2021-06-13 Released chaac v6.2 to JLCPCB
    [chaac.kicad_pcb, chaac.sch]
2021-07-03 Changed resistors for charger to get 200mA charge rate
    [chaac.sch]
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2021-07-12 Reset packets now working!
    [app_main.c, chaac_reset.py]
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2021-07-21 Make sure we don't crash if device data isn't available for date range
2021-07-22 Retire old chaac fw, chaac_new->chaac
    [st_nucleo_l4.cfg, st_nucleo_l4_hardreset.cfg, stlink-mod.cfg]
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2021-07-29 Fix wind direction (deg) key
    [chaac_logger.py]
2021-07-29 JK, that didn't work. 🤦‍♂️
    Changing chaac to take both wind_dir and wind_dir_deg
    [chaac_logger.py]
2021-07-29 Do proper wind direction averaging and fix wind direction
    Also, join devices with same name in plots.
    Don't show status if data is older than one day
2021-07-31 Add a bunch of features to chaac_usb_lora
    Enter dfu on command
    Reboot on command
    Send ping/pong
    added chaac_util.py
    [app_main.c, chaac_util.py]
2021-08-01 Make sure lora_usb_rx goes into rx mode after an rx error 🤦‍♂️
    Also added way of getting memfault data from usb_lora
    [app_main.c, chaac_util.py]
2021-08-01 Fix db and don't plot rainless samples
2024-07-01 Start working on Chaac ng!
    Schematic mostly done, layout in progress
    [chaac_ng.kicad_pcb, chaac_ng.kicad_sch]
2024-07-03 More placement/routing
    [chaac_ng.kicad_pcb, chaac_ng.kicad_sch]
2024-07-06 More layout/routing
    [chaac_ng.kicad_pcb]
2024-07-07 Releaed to JLCPCB
    [chaac_ng.kicad_pcb, chaac_ng.kicad_sch]
2024-07-21 Chaac ng 7.1
    [chaac_ng.kicad_pcb, chaac_ng.kicad_sch]
2024-07-22 Released v7.1 to JLCPCB
    [chaac_ng.kicad_pcb, chaac_ng.kicad_sch]
2024-07-22 Fix the silkscreen...
    [chaac_ng.kicad_pcb]
2024-07-25 Fix ADC reference voltage
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2026-10-11 Replace conda firmware env with toolchain dir + venv
    Arm GNU Toolchain 13.2.rel1 is expected under ~/toolchains; CMake and
    Ninja come from a pinned venv. env.sh sets both up. Also add udev rules
    for the STM32 DFU bootloader and the CDC port (uaccess, ModemManager
    ignore) and document the build/flash steps.
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2026-10-11 Add chaac.db history import for the HA integration
    import_chaac_db.py copies hour_samples into each Chaac sensor's own
    long-term statistics over the websocket API, reusing the live
    statistics metadata so old and new data form one series. By default it
    only imports hours before a sensor's first existing hour; --until sets
    the cutoff explicitly and replaces what is there.
    Rain is imported as a running total from 0 (HA takes the first row's
    change against 0), then the live sums are shifted up by the imported
    total with adjust_sum_statistics. The shift is skipped when already
    applied, and the script waits for the recorder queue so reruns can tell.
    wind_gust is skipped since the old logger alway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
2026-10-11 Import chaac.db history from the integration's setup flow
    Replaces the standalone import script. Adding the receiver now has an
    optional step to upload a chaac.db; the import runs once at setup,
    before the receiver starts:
    - stations from the DB get devices up front, named from the DB
    - hourly history goes into each sensor's own statistics; circular wind
    direction rows carry mean_weight, without which HA's daily/monthly
    rollups of the imported hours came out empty
    - each rain meter starts at the imported total. Nothing is recorded for
    it yet, so the recorder takes that as its starting point instead of
    rain, and the reading continues across the switch instead of dropping
    to 0
    - the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
2026-10-22 ha_chaac: reboot the receiver when it goes quiet
    Older usb_lora firmware can stop delivering radio packets while USB
    keeps working. After 10 minutes without a frame, send the reboot USB
    command, backing off up to 6 hours while it stays quiet.
2026-10-22 ha_chaac: add a daily rain sensor and hide the lifetime total
    The lifetime rain total only exists so statistics can give rain per
    period; nobody wants to look at it. Hide it by default and add a
    "Rain today" sensor that resets at local midnight.
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

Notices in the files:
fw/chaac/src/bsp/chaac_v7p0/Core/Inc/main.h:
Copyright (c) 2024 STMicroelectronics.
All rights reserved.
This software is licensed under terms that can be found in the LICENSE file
